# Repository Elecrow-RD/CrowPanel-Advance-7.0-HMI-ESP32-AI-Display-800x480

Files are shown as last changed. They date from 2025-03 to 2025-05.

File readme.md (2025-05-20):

## Menu
### 1, Product picture
### 2, Product version number
### 3, product information
### 4, Use the driver module
### 5,Quick Start
### 6,Folder structure.
### 7,Pin definition
### 8,Guidelines for downloading some of the files from the github repository

### 1, Product picture

Crowpanel Advance ESP32 HMI AI Display

#### 2, Product version number

| | Hardware | Software | Remark |
| ---- | --- | --- | --- |
| 1 | V1.0 | V1.0 | old |
| 2 | V1.2 | V1.2 | latest |

### 3, product information

| Main Chip-ESP32-S3-WROOM-1-N16R8 | |
| --- | --- |
| CPU/SoC | high-performance Xtensa 32-bit LX7 dual-core processor, with up to 240MHz |
| System Memory | 512KB SRAM、8M PSRAM |
| Memory | 16M Flash，384KB ROM |
| Development Language | MicroPython、C/C++ |
| Development Environment | ESP-IDF、Arduino IDE、PlatformIO、Micro Python、LVGL |
| **Screen** | |
| Size | 7.0 inch |
| Diver IC | SC7277 |
| Resolution | 800*480 |
| Display Panel | IPS Panel |
| Touch Panel | Capacitive Single Touch |
| Viewing Angle | 178° |
| Brightness | 400 cd/m²(Typ.) |
| Color Depth | 16-bit |
| **Wireless Communication - Onboard Antenna** | |
| WiFi | Support 2.4GHz, 802.11a/b/g/n |
| Bluetooth | Support Bluetooth 5.0 and BLE |
| Other | **Zigbee、LoRa、nRF2401、Matter、Thread and Wi-Fi 6 (Optional)** |
| **Interface/Function** | |
| Interface | USB port, UART, I2C, SD card slot, battery socket, speaker port, microphone, etc. |
| Function | RTC clock, audio amplifier, volume control, battery charge management, USB to UART, etc. |
| **Button/LED Indicator** | |
| Reset Button | Yes, press to reset the device |
| Boot Button | Yes, press and hold the power button to burn the program |
| PWR | Power indicator |
| CHG | Lithium battery charging status, completion indication |
| **Other** | |
| Installation method | Back hanging, fixed hole |
| Operating temperature | -20~70 °C |
| Storage temperature | -30~80 °C |
| Power Input | 5V/2A, USB or UART terminal |
| Active Area | 156mm*87mm |
| Dimensions | 181.26*108.36*16mm |

### 4, Use the driver module

| Name | dependency library |
| ---- | --- |
| LVGL | lvgl/lvgl@8.3.3 |
| | Adafruit GFX Library<br/>version=1.11.0 |

### 5,Quick Start
### Arduino IDE starts

#### Teaching Case Path：./example/example_code7.0

1.Download the library files used by this product to the 'libraries' folder.

C:\Users\Documents\Arduino\libraries\



2.Open the Arduino IDE



3.Open the code configuration environment and burn it



### ESP-IDF starts

#### Teaching Case Path：./example/idf_code

1.Right-click on an empty space in the project folder and select "Open with VS Code" to open the project.


2.In the IDF plug-in, select the port, then compile and flash


### 6,Folder structure.

|--3D file： Contains 3D model files (.stp) for the hardware. These files can be used for visualization, enclosure design, or integration into CAD software.

|--Datasheet: Includes datasheets for components used in the project, providing detailed specifications, electrical characteristics, and pin configurations.

|--Eagle_SCH&PCB: Contains **Eagle CAD** schematic (`.sch`) and PCB layout (`.brd`) files. These are used for circuit design and PCB manufacturing.

|--example: Provides example code and projects to demonstrate how to use the hardware and libraries. These examples help users get started quickly.

|--factory_firmware: Stores pre-compiled factory firmware that can be directly flashed onto the device. This ensures the device runs the default functionality.

|--factory_sourcecode:  Contains the source code for the factory firmware, allowing users to modify and rebuild the firmware as needed.

|--libraries: Includes necessary libraries required for compiling and running the project. These libraries provide drivers and additional functionalities for the hardware.

|--Squareline_studio Instructions for use: Squareline_studio instructions: Demonstrate the use of squareline studio.

### 7,Pin definition

#define HSPI_MISO  4
#define HSPI_MOSI  6
#define HSPI_SCLK  5
#define HSPI_SS    19

#define SD_MOSI 6
#define SD_MISO 4
#define SD_SCK  5
#define SD_CS   7 //The chip selector pin is not connected to IO

#define I2S_DOUT 12
#define I2S_BCLK 13
#define I2S_LRC 11

cfg.pin_sclk = 42;  // SPI、SCLK

cfg.pin_mosi = 39;  // SPI、CLK

cfg.pin_miso = -1;  // SPI、MISO

cfg.pin_dc = 41; 

#define TOUCH_GT911_SCL 16
#define TOUCH_GT911_SDA 15

### 8,Guidelines for downloading some of the files from the github repository

##### 1, open the link in your browser: https://downgit.github.io/

##### 2, paste the URL of the GitHub destination folder in the input box (example format: `https://github.com/username/repository name/tree/branch name/folder path`)

github_download1

##### 3, even a that way to download the file.

①Click the “Create Download Link” button to create a download link, copy the link and open it with your browser to download the contents of the corresponding folder directly.

github_download2

②Click Download, and you can also download it directly.

github_download3

#### Note: DownGit downloads are stored by default in **your browser's default downloads folder**, usually:

- **Windows**: `C:\Users\your username\Downloads\` (downloads folder)
- **macOS**: `~/Downloads/` (downloads folder)
- **Linux**: `~/Downloads/` (Downloads folder)

If you change the default download path in your browser, the file will be stored in the download location you set. You can find the downloaded file path in your browser's **Download History** (shortcut `Ctrl + J` or `Cmd + J`).

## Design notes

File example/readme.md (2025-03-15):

## **The basic tutorial case is divided into 1-11 lessons:**

1,Introduction to CrowPanel-Advance-HMI Screen

2,Introduce the screen user interface and external speakers for playing songs

3,Use LVGL library to create UI interface and light up lights

4,SD card stores images and displays them locally

5,Port Introduction

6,nRF2401 communication

7,wirelessmodule_lorawan

 8,Elementary chatbot（text-to-text）

 9,wirelessmodule_zigbee

 10,Build AI Chatbot

 11,LoRa Meshtastic

### Documentation tutorial link：

https://www.elecrow.com/pub/wiki/HMI_Display_course.html

### YouTube tutorial link:

https://www.youtube.com/playlist?list=PLwh4PlcPx2Gfrtm7TmlARyF4ccTmIy-gK

### Product purchase link:

https://www.elecrow.com/crowpanel-advance-7-0-hmi-esp32-ai-display-800x480-artificial-intelligent-ips-touch-screen-support-meshtastic-and-arduino-lvgl-micropython.ht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

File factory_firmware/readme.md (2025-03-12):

# How to install the factory demo firmware with flash download tool?

#### 1.Preparation:

- USB C cable
- Laptop/PC
- Crowpanel Advance HMI ESP32 AI Display
- Flash download tool

Check whether the materials on the PCBA board are defective. Such as less material, false welding, tin and other bad phenomena.

#### 2.Flash the firmware 

##### Step1 Connect the ESP32 display to the laptop/PC with USB-C cable. The power indicator will light up.

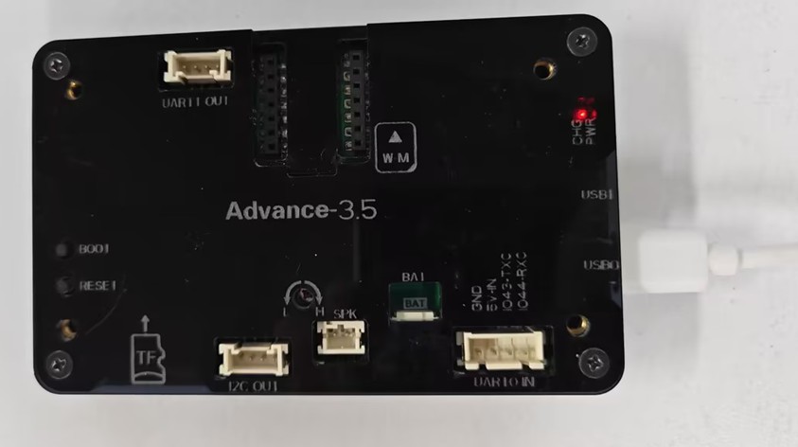
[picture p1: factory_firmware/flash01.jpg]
flash01


##### Step2 Open the flash download tool. 

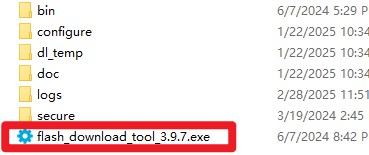
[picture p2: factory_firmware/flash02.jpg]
flash02


For the  Crowpanel Advance HMI ESP32 AI Display, the chip select ESP32-S3:

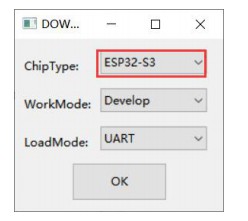
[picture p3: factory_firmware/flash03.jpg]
flash03


##### Step3

①Choose the firmware files;

flash0

②Enter the address: 

boot_app0.bin------0xe000

xxxx.ino.bin--------0x10000

xxxx.ino.bootloader.bin------0x0

xxxx.ino.partitions.bin-------0x8000

③Check the firmware files;

④Select the correct port number;

⑤Click “Start” to download

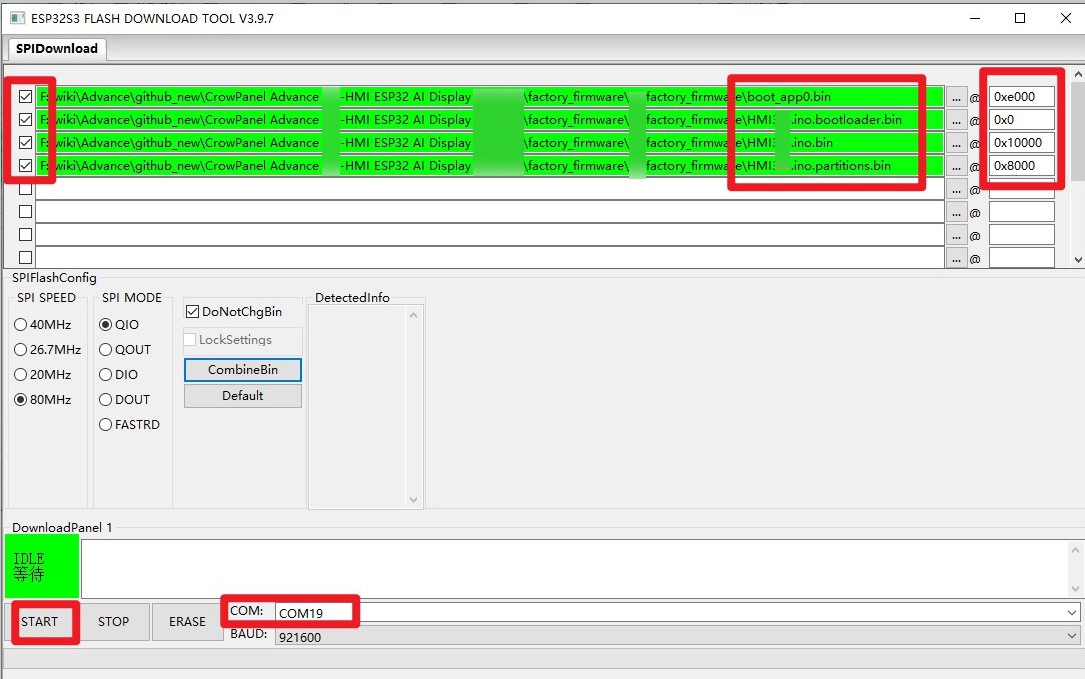
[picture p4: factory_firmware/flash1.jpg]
flash1


##### Step4 After the download is complete, blue FINISH will be displayed, and the progress bar at the bottom shows that it has come to an end.

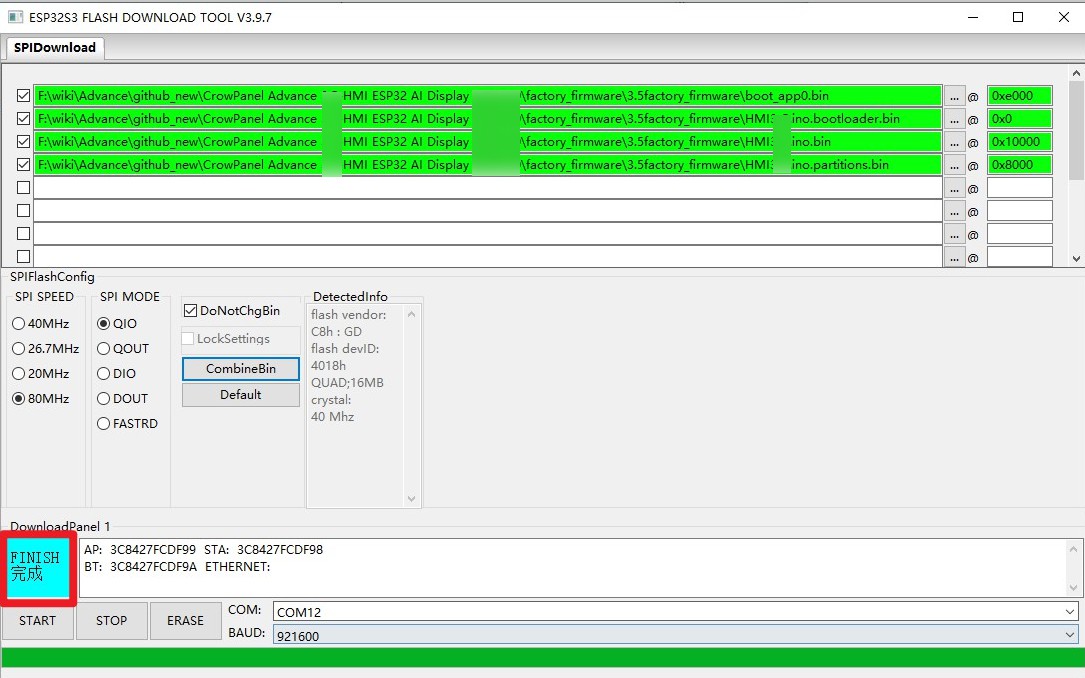
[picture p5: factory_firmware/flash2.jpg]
flash2


##### Step5 Press the reset button to show the demo.

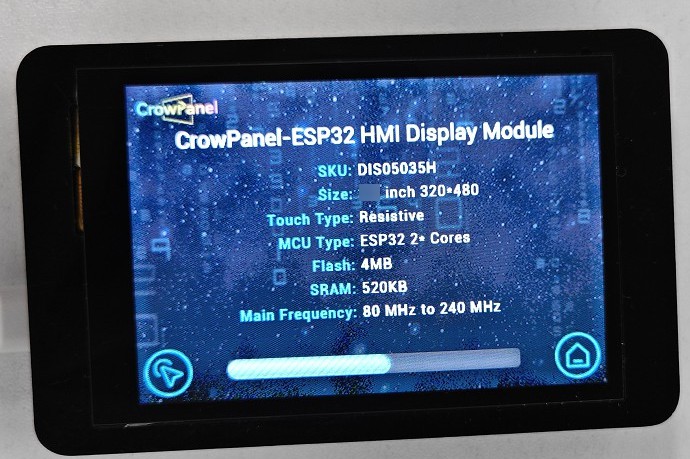
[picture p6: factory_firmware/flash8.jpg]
flash8


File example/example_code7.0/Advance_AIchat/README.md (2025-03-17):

# **AI real-time voice communication example**

we will integrate the CrowPanel Advance ESP32 display with a Large Language Model (LLM) and use a local computer running Python server code to process data. The processed data is then sent to the CrowPanel Advance AI display, which runs on Arduino code, for visualization. This setup enables seamless voice interaction with AI, showcasing the power of combining advanced hardware and software solutions.

***\*Note:\**** 

***\*ESP32 version 3.0.2\****

***\*Python version 3.10.6\****

### **How to use example**

You can find detailed video tutorials at the bottom of the page.

***\*First\****, identify the model you need to access and register an account on the model’s official website to obtain the access key.

***\*Then\**** uncomment the corresponding model code in the 'llm_openai.py' file and replace the placeholder with the key.

Ensure that your Python version is 3.10.6. Then, open the Command Prompt (or terminal) and navigate to the code folder. Run the following commands to create a virtual environment and install the related dependencies.



cmd

```
python -m venv venv
.\venv\Scripts\activate
python -m pip install --upgrade pip
pip install requrements-i
pip install openai dashscope
```

After installing the dependencies, you can run the 'ws.py' script to execute the saerver code.

The next step is to modify the ESP32 device code. We only need to change the server's IP address to ensure the device is on the same LAN as the WiFi network.



***\*Configuration parameter：\****



After burning successfully, the device will appear as connected on the server side and be ready to communicate. During communication, you can press the boot button to interrupt the current session and initiate a new one.

### **How to add Arduino libraries**

Replace the libraries file with the following path:

C:\Users\user name\Documents\Arduio\libraries

***\*Note\****: The 'user name' here is the same as the user computer account name.

## **Video tutorial link**：

 https://youtu.be/oIz41dyDqjo # **AI real-time voice communication example**

we will integrate the CrowPanel Advance ESP32 display with a Large Language Model (LLM) and use a local computer running Python server code to process data. The processed data is then sent to the CrowPanel Advance AI display, which runs on Arduino code, for visualization. This setup enables seamless voice interaction with AI, showcasing the power of combining advanced hardware and software solutions.

***\*Note:\**** 

***\*ESP32 version 3.0.2\****

***\*Python version 3.10.6\****

### **How to use example**

You can find detailed video tutorials at the bottom of the page.

***\*First\****, identify the model you need to access and register an account on the model’s official website to obtain the access key.

***\*Then\**** uncomment the corresponding model code in the 'llm_openai.py' file and replace the placeholder with the key.

Ensure that your Python version is 3.10.6. Then, open the Command Prompt (or terminal) and navigate to the code folder. Run the following commands to create a virtual environment and install the related dependencies.



cmd

```
python -m venv venv
.\venv\Scripts\activate
python -m pip install --upgrade pip
pip install requrements-i
pip install openai dashscope
```

After installing the dependencies, you can run the 'ws.py' script to execute the saerver code.

The next step is to modify the ESP32 device code. We only need to change the server's IP address to ensure the device is on the same LAN as the WiFi network.



***\*Configuration parameter：\****



After burning successfully, the device will appear as connected on the server side and be ready to communicate. During communication, you can press the boot button to interrupt the current session and initiate a new one.

### **How to add Arduino libraries**

Replace the libraries file with the following path:

C:\Users\user name\Documents\Arduio\libraries

***\*Note\****: The 'user name' here is the same as the user computer account name.

## **Video tutorial link**：

 https://youtu.be/oIz41dyDqjo

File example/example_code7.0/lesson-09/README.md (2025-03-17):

# **The ESP32-H2 module utilizes ZigBee technology to build a wireless Internet of Things** **example**

To complete this case, you need to refer to the detailed documentation tutorial, learn to burn code to utilizes ZigBee technology to build a wireless Internet and make the coordinator sends information to the terminal. Detailed documentation tutorials can be found at the bottom of the page.

***\*Note: All examples run on ESP32 version 3.0.2.\****

### **How to use example**

Learn how to set up the development board for serial communication with the wireless module. Learn how to use the official sample programs of ESP32-H2 to configure the wireless modules as a coordinator and a terminal node. After opening the sample code in the relevant code file with Arduino IDE.set the required configuration parameters and program it onto the development board.

***\*Configuration parameter：\****

For Coordinator configuration

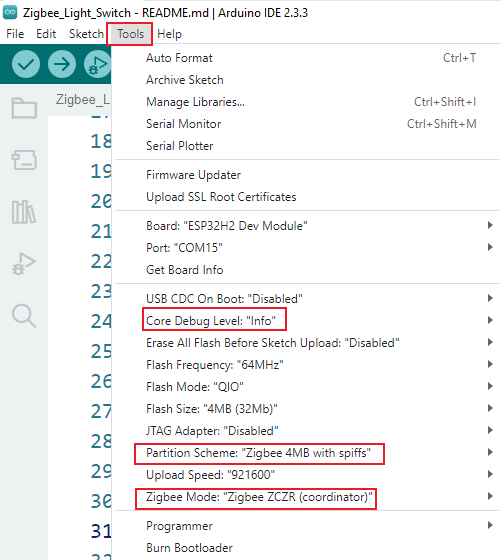
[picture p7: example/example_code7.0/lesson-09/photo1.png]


For Terminal device configuration

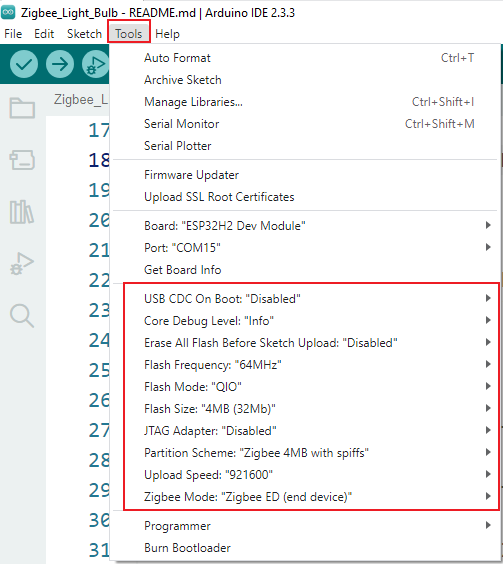
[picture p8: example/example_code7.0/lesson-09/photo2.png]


For HMI Advance AI Display Configuration

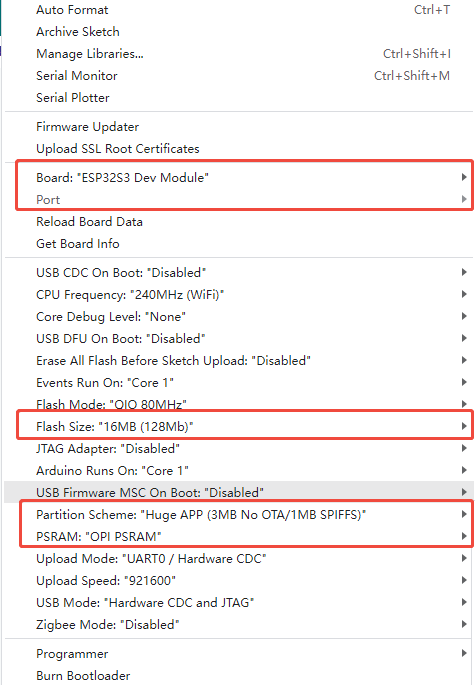
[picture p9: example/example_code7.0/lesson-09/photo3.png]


### **How to add Arduino libraries**

Replace the libraries file with the following path:

C:\Users\user name\Documents\Arduio\libraries

***\*Note\****: The 'user name' here is the same as the user computer account name.

## **Documentation tutorial link****：**

## https://www.elecrow.com/wiki/9.ZigBee.html

## **Video** **tutorial link****：**
https://www.youtube.com/watch?v=UfxxT23T_bk

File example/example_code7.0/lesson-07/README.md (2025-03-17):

# **The nRF2401 wireless module is used to receive and transmit signals** **example**

To complete this case, you need to refer to the detailed documentation tutorial, learn to connect to the gateway, and then burn code to send AT instructions. Detailed documentation tutorials can be found at the bottom of the page.

***\*Note: All examples run on ESP32 version 3.0.2.\****

### **How to use example**

Learn how to set up a gateway.After opening the sample code in the relevant code file with Arduino IDE.set the required configuration parameters and program it onto the development board

***\*Configuration parameter：\****

图片7-1

**Note**:Before burning the code, be sure to set the switch on the back of the product to WM mode(0 1).

### **How to add Arduino libraries**

Replace the libraries file with the following path:

C:\Users\user name\Documents\Arduio\libraries

***\*Note\****: The 'user name' here is the same as the user computer account name.

## **Documentation tutorial link**：

https://www.elecrow.com/pub/wiki/7.Advance_wirelessmodule_lorawan.html

## **Video** **tutorial link**：
https://youtu.be/7SWwTssfDV8

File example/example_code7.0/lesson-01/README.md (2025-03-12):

# **Hello world example**

This is a simple example of displaying “Hello world” in the serial debugging window using ESP32 version 3.0.2.

***\*Note: All subsequent examples run on ESP32 version 3.0.2.\****

### **How to use example**

After opening the sample code in the relevant code file with Arduino IDE, set the required configuration parameters and program it onto the development board

***\*Configuration parameter：\****



### **How to add Arduino libraries**

No additional libraries are required for this lesson, so no imports are needed.

## **Documentation tutorial link**：

https://www.elecrow.com/pub/wiki/1_Introduction_to_CrowPanel-Advance-HMI_Screen.html

## **Video** **tutorial link**：

https://www.youtube.com/watch?v=W3LHGZRx7Jw&list=PLwh4PlcPx2Gfrtm7TmlARyF4ccTmIy-gK&index=1&t=42s

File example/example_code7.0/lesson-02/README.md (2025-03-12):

# **Play Internet music example**

This is an example of a program that uses a speaker to play an MP3 file from the Internet.

***\*Note: All examples run on ESP32 version 3.0.2.\****

### **How to use example**

After opening the sample code in the relevant code file with Arduino IDE.

Set up your wifi in code.

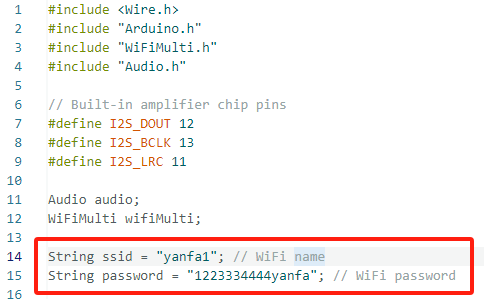
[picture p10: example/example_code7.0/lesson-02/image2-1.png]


set the required configuration parameters and program it onto the development board

***\*Configuration parameter：\****



After burning the program successfully, insert the speaker into the designated port on the development board.

**Note**:Before burning the code, be sure to set the switch on the back of the product to MIC&SPK mode(0 0).

### **How to add Arduino libraries**

Replace the libraries file with the following path:

C:\Users\user name\Documents\Arduio\libraries

***\*Note\****: The 'user name' here is the same as the user computer account name.

## **Documentation tutorial link**：

https://www.elecrow.com/pub/wiki/4.3_2_Introduce_the_screen_user_interface_and_external_speakers_for_playing_songs.html

## **Video** **tutorial link**：

https://www.youtube.com/watch?v=1lY-Cu6dnaQ&list=PLwh4PlcPx2Gfrtm7TmlARyF4ccTmIy-gK&index=2

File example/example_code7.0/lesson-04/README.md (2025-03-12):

# **Use an SD card to store and display pictures on the device example**

In this case, images are stored on an SD card and displayed on the Advanced AI screen.

***\*Note: All examples run on ESP32 version 3.0.2.\****

### **How to use example**

After opening the sample code in the relevant code file with Arduino IDE.set the required configuration parameters and program it onto the development board

***\*Configuration parameter：\****

图片4-1

**Note**:Before burning the code, be sure to set the switch on the back of the product to TF Card mode(1 0).

### **How to add Arduino libraries**

Replace the libraries file with the following path:

C:\Users\user name\Documents\Arduio\libraries

***\*Note\****: The 'user name' here is the same as the user computer account name.

## **Documentation tutorial link**：

https://www.elecrow.com/pub/wiki/4.3_4_SD_card_stores_images_and_displays_them_locally.html

## **Video** **tutorial link**：

https://www.youtube.com/watch?v=qSlhvBrq0_w&list=PLwh4PlcPx2Gfrtm7TmlARyF4ccTmIy-gK&index=4

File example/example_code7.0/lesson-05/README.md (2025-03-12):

# ****Connect to the sensor via the port to read temperature and humidity measurements example****

In this case, we connect the temperature and humidity sensor through the port to obtain the environmental temperature and humidity, and display the data on the Advanced AI screen in real time.

***\*Note: All examples run on ESP32 version 3.0.2.\****

### **How to use example**

After opening the sample code in the relevant code file with Arduino IDE.set the required configuration parameters and program it onto the development board

***\*Configuration parameter：\****

图片5-1

### **How to add Arduino libraries**

Replace the libraries file with the following path:

C:\Users\user name\Documents\Arduio\libraries

***\*Note\****: The 'user name' here is the same as the user computer account name.

## **Documentation tutorial link**：

https://www.elecrow.com/pub/wiki/4.3_5_Port_Introduction.html

## **Video** **tutorial link**：

https://www.youtube.com/watch?v=WM8ZcJ9OYKw&list=PLwh4PlcPx2Gfrtm7TmlARyF4ccTmIy-gK&index=5

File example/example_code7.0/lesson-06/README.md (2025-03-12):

# **The nRF2401 wireless module is used to receive and transmit signals** **example**

In this case, two nRF24L01 wireless modules are employed, with one module transmitting signals and the other receiving signals.

***\*Note: All examples run on ESP32 version 3.0.2.\****

### **How to use example**

After opening the sample code in the relevant code file with Arduino IDE.set the required configuration parameters and program it onto the development board

***\*Configuration parameter：\****

图片6-1

**Note**:Before burning the code, be sure to set the switch on the back of the product to WM mode(0 1).

### **How to add Arduino libraries**

Replace the libraries file with the following path:

C:\Users\user name\Documents\Arduio\libraries

***\*Note\****: The 'user name' here is the same as the user computer account name.

## **Documentation tutorial link**：

https://www.elecrow.com/pub/wiki/4.3_6_NRF2401_communication.html

## **Video** **tutorial link**：

https://www.youtube.com/watch?v=PHzW8t038Qo&list=PLwh4PlcPx2Gfrtm7TmlARyF4ccTmIy-gK&index=6

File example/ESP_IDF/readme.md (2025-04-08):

##### ESP_IDF code program are in the google disk, please click on the link to download it directly!

#### link：

https://drive.google.com/drive/folders/1hEXyH14QeDgVdENxUfiYBQVCTbMbI6v9?usp=sharing

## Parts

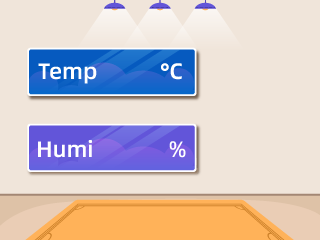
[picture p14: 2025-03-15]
example/example_code7.0/lesson-05/source material/320x240/background.png

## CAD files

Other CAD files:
Datasheet/LI070DE42Y_0812.dwg

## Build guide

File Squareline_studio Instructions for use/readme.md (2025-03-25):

# Use SquareLine Studio and LVGL libraries to create a UI interface to light the lights

## **1.** Introduce LVGL

------

LVGL (LittlevGL) is an open-source, lightweight, high-performance embedded graphics library designed specifically for devices with limited resources. It supports multi platform porting, provides rich controls, animations, touch support, and highly customizable styles, suitable for fields such as smart homes, industrial equipment, medical instruments, etc. LVGL is centered around modular design and can run on bare metal or operating systems, accelerating GUI development through powerful community support and tools such as SquareLine Studio.



SquareLine Studio is a next-generation user interface (UI) solution for individuals and professionals, allowing users to quickly and easily design and develop aesthetically pleasing UI for embedded devices. This software provides integrated design, prototyping, and development capabilities, supporting the export of platform independent C or MicroPython code for LVGL (Lightweight Graphics Library), which can be compiled and run on any vendor's device.



## 2.Install SquareLine Studio

------

### **2.1** Installation Guide

Enter the https://squareline.io/ to download the SquareLine installation file.



Download the version 1.4.0



Double-click the setup.exe file.



Click install.



Wait for installation.



Installation finish.



There is a 30-day trial period for the first time you use it. Please follow the prompts to register an account. You will continue to use it when you log in to your account next time.



### **2.2** Software Function Introduction

Open the software

The historical project page: open the project built earlier.



Create a project page: choose different platforms according to different hardware of the project.



###### When select the Arduino framwork, there's only one option "Arduino with TFT_eSPI". By choosing this, the squareline studio will generate a template code suitable for the TFT_eSPI library. However, squareline studio not only supports the TFT_eSPI library, it supports a variety of libraries to suit different hardware and application needs. For example, Adafruit_GFX library, LovyanGFX etc.[¶](https://www.elecrow.com/pub/wiki/3.5_3_Use_LVGL_library_to_create_UI_interface_and_light_up_lights.html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)

###### After using SLS to generate UI code, we then use different graphics libraries according to different hardware and modify the corresponding code to display the content you design.[¶](https://www.elecrow.com/pub/wiki/3.5_3_Use_LVGL_library_to_create_UI_interface_and_light_up_lights.html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)

Example page. This page has several official examples for reference.



The project settings bar is used to make basic settings for the project, including property settings such as project name, screen size, display angle, etc.



###### Note： Please select the corresponding resolution and color depth according to the screen specifications.[¶](https://www.elecrow.com/pub/wiki/3.5_3_Use_LVGL_library_to_create_UI_interface_and_light_up_lights.html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)



##### ①Toolbar, including File, Export, and Help. Basic file operation bar, create or open files, export UI files and other operations. Click help and there are related introductory documents.

##### ②Screen bar, the project screen will be listed here.

##### ③Widget area, all widgets are here and can be selected and used according to project needs.

##### ④Hierarchy area, it will show every widget used in each screen.

##### ⑤This area shows the actual display effect, you can adjust the widgets or screen here.

##### ⑥Material column, the added materials are displayed here.

##### ⑦Setting bar, where you can make basic settings for each part, including the basic attributes and trigger operations of the part.

##### ⑧Theme bar, different themes can be set.

## 3 Use SquareLine Studio to create UI control interfaces

------

Firstly, open the SquareLine Studio software and create a case study



Choose the correct resolution based on the different sizes you are using



Here, I take a 5.0-inch screen as an example. After determining the resolution, I fill it in



After selecting the parameters, click Create



Open the photo of the desk lamp we provided and add it in. (Of course, you can also choose the image you want to use)





The lamp_28 image size is available for both 2.4-inch and 2.8-inch screens.

Table_1amp image sizes are available for 3.5-inch, 4.3-inch, 5.0-inch, and 7-inch screens.



After adding it, drag and drop the image in.



The task we need to complete is to turn on and off the lights by clicking on the buttons on the graphical interface. So we need to design two buttons

From the left sidebar, select Button and drag it into the interface.



You can adjust the border of the button with the mouse, which can adjust the size of the button, and you can also drag and drop the button to adjust its position.

Then, by selecting Background, choose the background color of the Button.





We have made the button patterns, and now we need to add labels to the button patterns in order to distinguish their functions.

Drag and drop from the left sidebar, select Label, and drag into the interface.



Modify the text content of the label



And modify the font size and text color of the text



The Button and Label have been designed. Click on the Hierarchy in the right-hand column and drag the Label onto the Button line to merge them into one.



At this point, if you drag the buttons again, you will find that they are dragged together

Next, we will copy a completed button, right-click, and paste it in.







Click the second button ON to change the text content to Off. Used to achieve the effect of turning off lights.



## **4** Add functions to the buttons to enable them to turn on and off lights

------

Select 'event' to add in the right sidebar



Select 'released' as the triggering condition and 'Call function' as the action.



After selecting, click ADD.

And add a function name to the CALL Function. (Customization is sufficient)



Similarly, add an event to the Off button. The operation process is the same as above.



After adding, run





## **5** UI interface design completed, exporting UI files for easy use in subsequent code

------

Click on Project Setting



Set export path





Complete the setup and export file



Copy and paste the exported code into the code folder we need to open





Then double-click BigInch_LVGL.ino and open it using Arduino IDE

## **6 Connect the light bulb and add code to control the light bulb to turn on and off**

------

Connect the light bulb at the UART1 interface



Observing the schematic diagram of this size, it is known that the pin for UART1 to control the light bulb to turn on and off is 19





A large-sized screen requires setting 19 pins as the output mode.

(Due to the fact that pin 19 in the circuit of large-sized products controls both the wireless module and the UART1 interface, it is necessary to switch the mode to 0 1)





And add the function of turning on and off the light bulb in the ui_ event. c file.

(When the On button is clicked, the light is on; when the Off button is clicked, the light is off)



## **7 Configure the code running environment and upload the code**

------

(!! Before uploading the code, please use different library files according to the size you are using. You can review the content of Lesson 2)

(For large-sized screens of 4.3 inches, 5.0 inches, and 7.0 inches, be sure to switch the mode to 0 1 state before uploading the code, because the pins of UART1 and W-M mode are both used in 0 1 mode, so that you can use the pins of UART1)





So you can see the UI interface you just designed



You can click the On and Off buttons to control the on/off of the lights





## 8 Code presentation

------

### 7.0 inches, 5.0 inches, 4.3 inches

```
#include "pins_config.h"
#include "LovyanGFX_Driver.h"

#include <Arduino.h>
#include <lvgl.h>
#include <Wire.h>
#include <SPI.h>

#include <stdbool.h>
#include <Adafruit_SSD1306.h>
#include <Adafruit_GFX.h>

/* Expand IO */
#include <TCA9534.h>
TCA9534 ioex;

LGFX gfx;

/* Change to your screen resolution */
static lv_disp_draw_buf_t draw_buf;
static lv_color_t *buf;
static lv_color_t *buf1;

uint16_t touch_x, touch_y;

//  Display refresh
void my_disp_flush(lv_disp_drv_t *disp, const lv_area_t *area, lv_color_t *color_p) {
  if (gfx.getStartCount() > 0) {
    gfx.endWrite();
  }
  gfx.pushImageDMA(area->x1, area->y1, area->x2 - area->x1 + 1, area->y2 - area->y1 + 1, (lgfx::rgb565_t *)&color_p->full);

  lv_disp_flush_ready(disp);  //    Tell lvgl that the refresh is complete
}

//  Read touch
void my_touchpad_read( lv_indev_drv_t * indev_driver, lv_indev_data_t * data )
{
  data->state = LV_INDEV_STATE_REL;// The state of data existence when releasing the finger
  bool touched = gfx.getTouch( &touch_x, &touch_y );
  if (touched)
  {
    data->state = LV_INDEV_STATE_PR;

    //  Set coordinates
    data->point.x = touch_x;
    data->point.y = touch_y;
  }
}

void setup()
{
  Serial.begin(115200); 

  pinMode(19, OUTPUT);

  Wire.begin(15, 16);
  delay(50);

  ioex.attach(Wire);
  ioex.setDeviceAddress(0x18);
  ioex.config(1, TCA9534::Config::OUT);
  ioex.config(2, TCA9534::Config::OUT);
  ioex.config(3, TCA9534::Config::OUT);
  ioex.config(4, TCA9534::Config::OUT);

  /* Turn on backlight*/
  ioex.output(1, TCA9534::Level::H);

  // GT911 power on timing ->Select 0x5D
  pinMode(1, OUTPUT);
  digitalWrite(1, LOW);
  ioex.output(2, TCA9534::Level::L);
  delay(20);
  ioex.output(2, TCA9534::Level::H);
  delay(100);
  pinMode(1, INPUT);
  /*end*/

  // Init Display
  gfx.init();
  gfx.initDMA();
  gfx.startWrite();
  gfx.fillScreen(TFT_BLACK);

  lv_init();
  size_t buffer_size = sizeof(lv_color_t) * LCD_H_RES * LCD_V_RES;
  buf = (lv_color_t *)heap_caps_malloc(buffer_size, MALLOC_CAP_SPIRAM);
  buf1 = (lv_color_t *)heap_caps_malloc(buffer_size, MALLOC_CAP_SPIRAM);

  lv_disp_draw_buf_init(&draw_buf, buf, buf1, LCD_H_RES * LCD_V_RES);

  // Initialize display
  static lv_disp_drv_t disp_drv;
  lv_disp_drv_init(&disp_drv);
  // Change the following lines to your display resolution
  disp_drv.hor_res = LCD_H_RES;
  disp_drv.ver_res = LCD_V_RES;
  disp_drv.flush_cb = my_disp_flush;
  disp_drv.draw_buf = &draw_buf;
  lv_disp_drv_register(&disp_drv);

  // Initialize input device driver program
  static lv_indev_drv_t indev_drv;
  lv_indev_drv_init(&indev_drv);
  indev_drv.type = LV_INDEV_TYPE_POINTER;
  indev_drv.read_cb = my_touchpad_read;
  lv_indev_drv_register(&indev_drv);

  delay(100);

  gfx.fillScreen(TFT_BLACK);
  // lv_demo_widgets();// Main UI interface
  ui_init();

  Serial.println( "Setup done" );
}

void loop()
{
  lv_timer_handler(); /* let the GUI do its work */
  delay(1);
}
```

**If your code compiles incorrectly, you can check if the ESP32 version number is correct. The ESP32 version number we need for this lesson is 3.0.2.**

new-1

**Secondly, please pay attention to replacing the corresponding size library file.**

**Select the appropriate library file based on the product screen size**

Path reference：C:\ESP32_Code\CrowPanel_Advanced_HMI\Arduino_lib Series Library

new-2

**I will use the Advance 7.0-inch product as an example for operation**

Copy the Libraries Advanced 7.0 folder

Open Arduino IDE runtime library file path

Reference path: C:\Users\14175\Documents\Arduino

new-3

Delete the existing libraries folder

new-4

Paste the copied library Advanced 7.0 folder into this path

new-5

Change the folder name to the original libraries

new-6

Library update completed, restart Arduino IDE.

**When using other sizes, changing the library file is the same operation**

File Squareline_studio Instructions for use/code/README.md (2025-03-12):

# **The touch screen lights up LED lights example**

This is an example of using the LVGL library to display an icon on the Advance AI screen, and to control the LED light when the icon is pressed.

***\*Note: All examples run on ESP32 version 3.0.2.\****

### **How to use example**

After opening the sample code in the relevant code file with Arduino IDE.set the required configuration parameters and program it onto the development board

***\*Configuration parameter：\****

图片3-1

### **How to add Arduino libraries**

Replace the libraries file with the following path:

C:\Users\user name\Documents\Arduio\libraries

***\*Note\****: The 'user name' here is the same as the user computer account name.

## **Documentation tutorial link**：

https://www.elecrow.com/pub/wiki/4.3_3_Use_LVGL_library_to_create_UI_interface_and_light_up_lights.html

## **Video** **tutorial link**：

https://www.youtube.com/watch?v=LXoKEsqQGDk&list=PLwh4PlcPx2Gfrtm7TmlARyF4ccTmIy-gK&index=3

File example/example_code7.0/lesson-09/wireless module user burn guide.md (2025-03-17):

## Wirless Module H2/C6 Single Board Burn-in Method

### 1.Tools to be prepared

| | Tools | quantities |
| ---- | --- | --- |
| 1 | Single Female DuPont Cable | 4 |
| 2 | Serial Module Tools | 1 |
| 3 | Wirless Module H2/C6 | 1 |
| 4 | Soldering Iron & Wire | |

 Single Female DuPont Cable
 


Wirless Module H2/C6



Serial modules (CH340/CP2102, etc. are fine)



### 2.Weld line.

The burn-in pins for the Wirless Module H2/C6 are the same, and the four wires that need to be soldered are located as follows：

（Arrow pointing up）

| RX | TX |
| ---- | ---- |
| | |
| | |
| | |
| 3V3  | |
| GND  | |
| | |

Module Pin Definition

The finished soldering is shown below.





### 3.Burning

RX is connected to TX of the serial module;

TX connection to the RX of the serial module;

3V3 connection to the 3V3 of the serial module;

GND connection to the GND of the serial module.

Connect the serial module to the computer and find the corresponding serial device number (e.g. COM7) in the Task Manager.



Open Arduino or open the corresponding serial port under any serial port tool.



Press and hold the BOOT key and then press the RST key to enter burn mode.



The serial monitor prints to enter burn-in mode.


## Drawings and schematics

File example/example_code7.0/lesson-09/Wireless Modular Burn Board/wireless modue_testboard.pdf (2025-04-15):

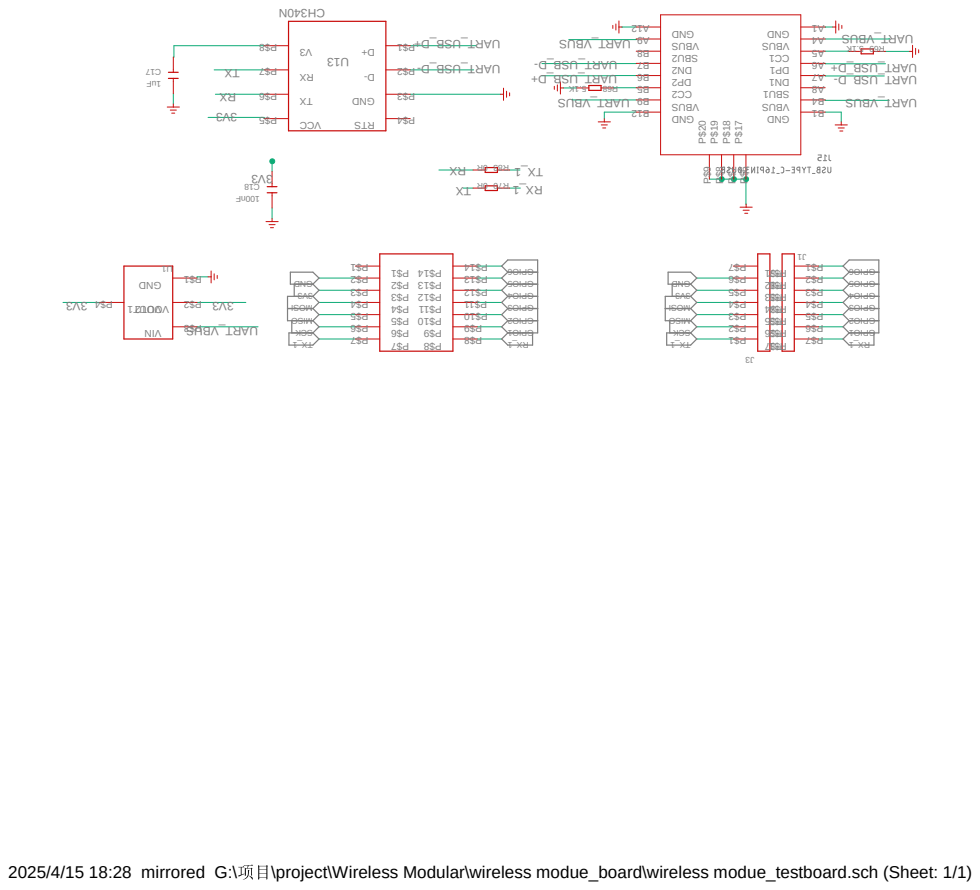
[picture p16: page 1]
2025/4/15 18:28 mirrored G:\; \project\Wireless Modular\wireless modue_board\wireless modue_testboard.sch (Sheet: 1/1); DNG 1A SUBV; 4A 1 CC 5A 1PD 6A 1 ND 7A 1 UBS; SUBV; 4B DNG 1B; DNG 21B; 2 UBS; DNG 21A; DNG 3$P; STR 4$P; CCV; DNG 1$P; 1TUOV; 2TUOV; DNG DNG; - D_BSU_TRAU; + D_BSU_TRAU; + D_BSU_TRAU SUBV_TRAU; SUBV_TRAU SUBV_TRAU; SUBV_TRAU; 3V3 3V3 3V3 I SOM I SOM OSI M OSI M

KCS 1 OI PG

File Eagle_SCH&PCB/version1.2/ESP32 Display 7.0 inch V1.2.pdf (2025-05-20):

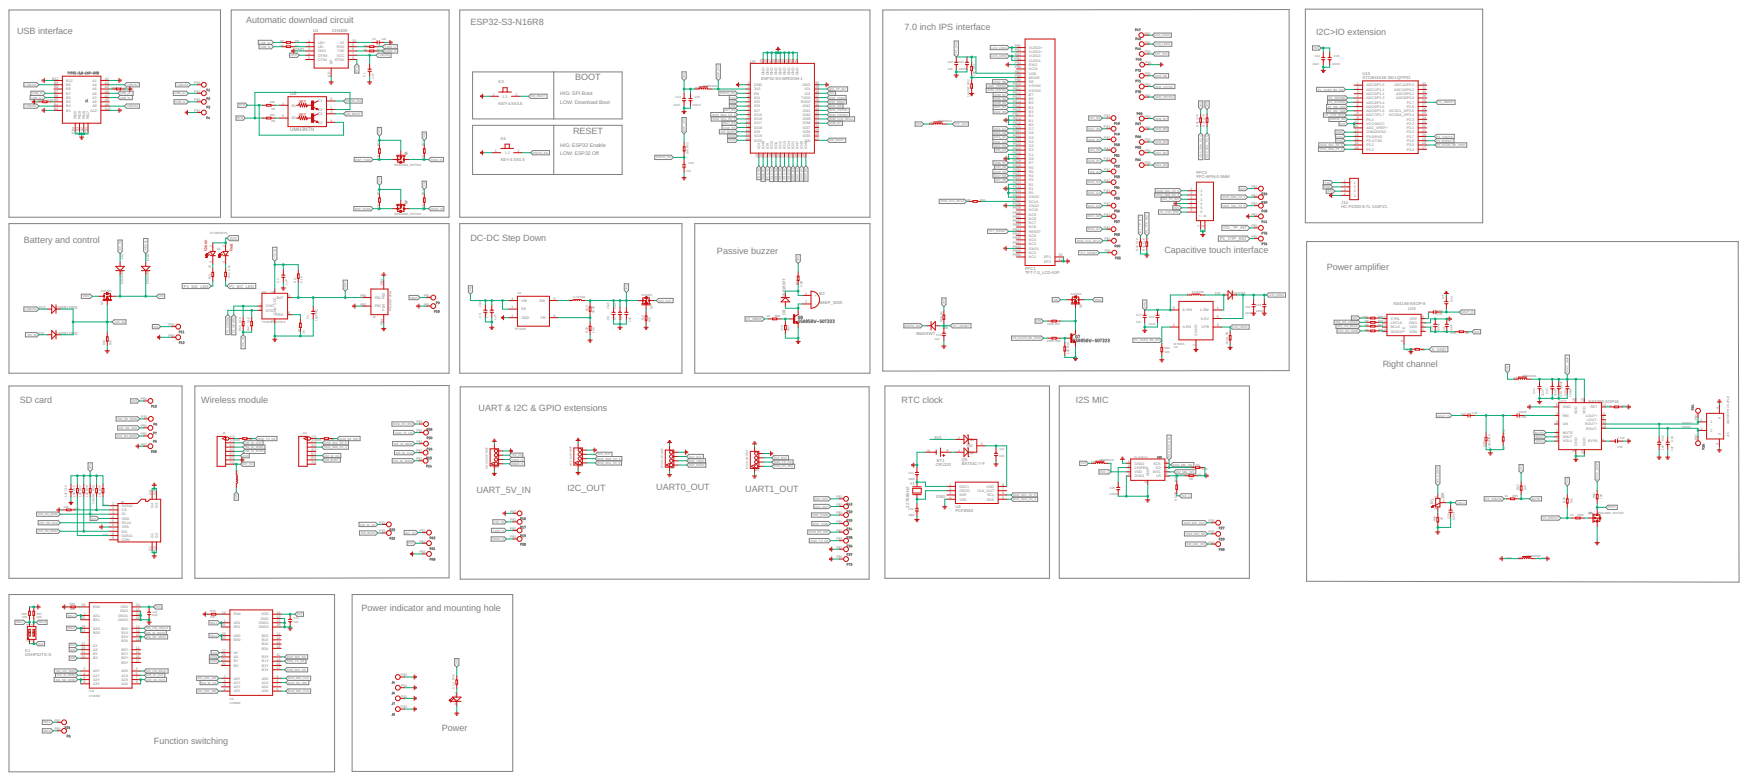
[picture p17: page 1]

DC-DC Step Down

Power indicator and mounting hole

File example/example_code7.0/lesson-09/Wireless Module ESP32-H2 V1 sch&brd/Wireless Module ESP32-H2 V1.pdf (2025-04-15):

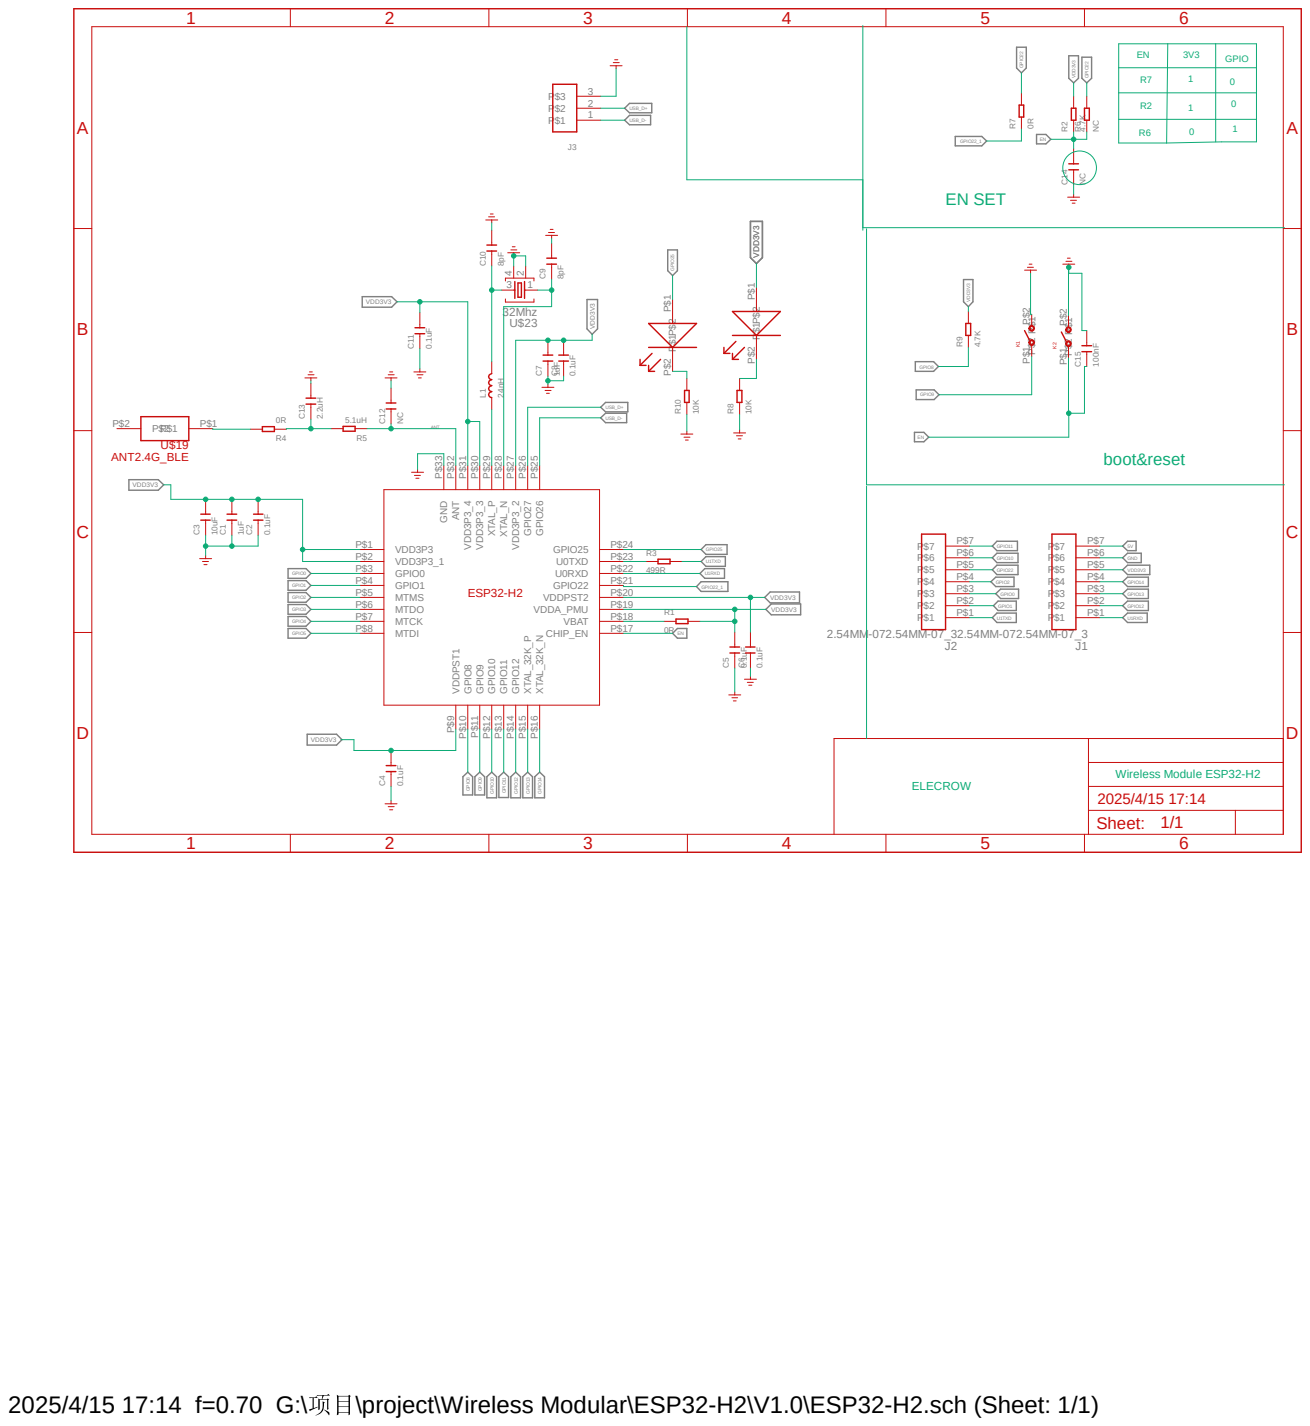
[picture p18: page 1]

EN | 3V3 | GPIO

EN SET

ELECROW

Sheet: 1/1

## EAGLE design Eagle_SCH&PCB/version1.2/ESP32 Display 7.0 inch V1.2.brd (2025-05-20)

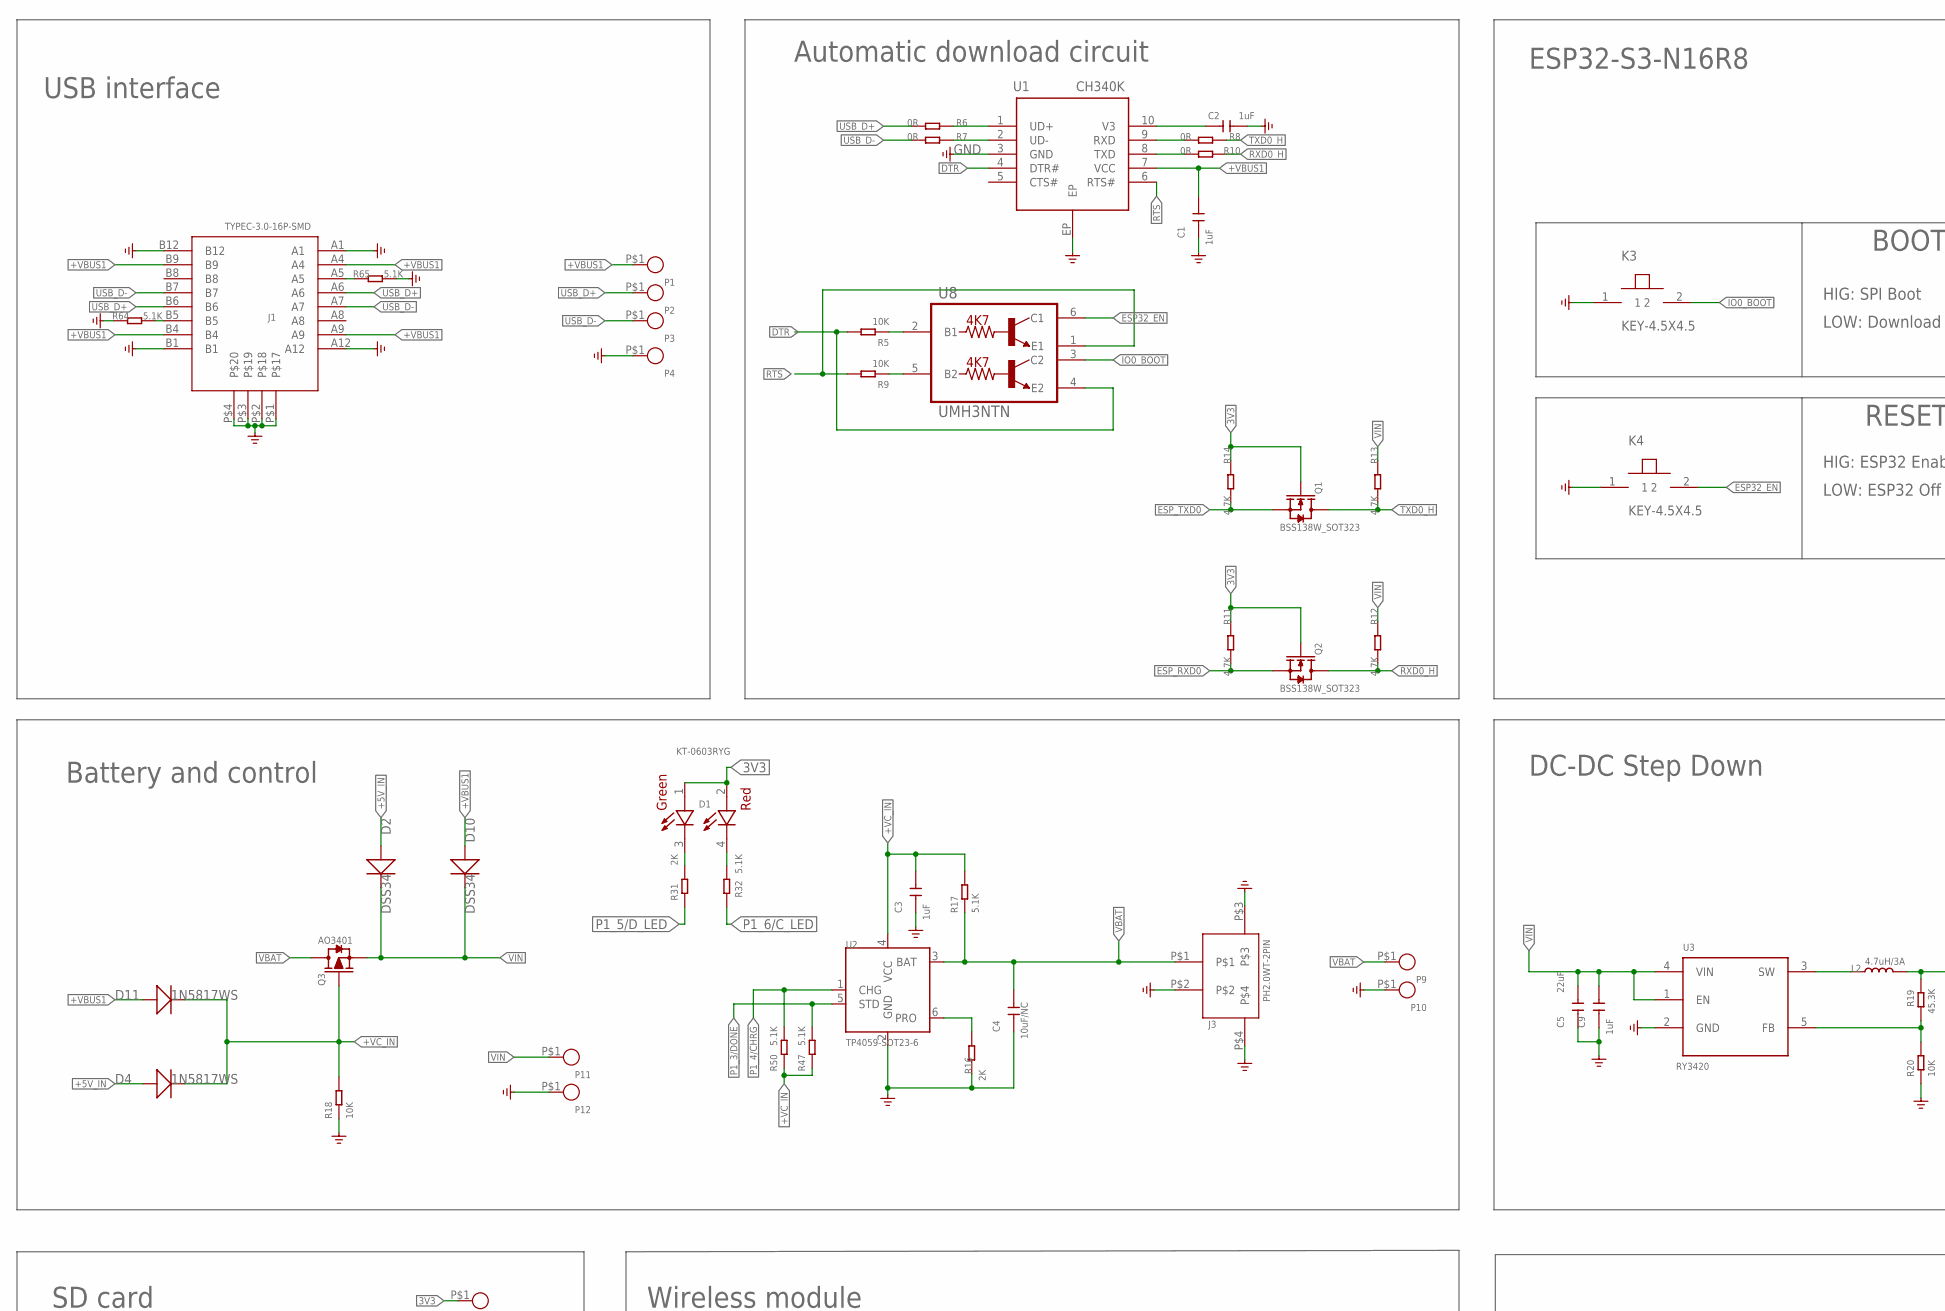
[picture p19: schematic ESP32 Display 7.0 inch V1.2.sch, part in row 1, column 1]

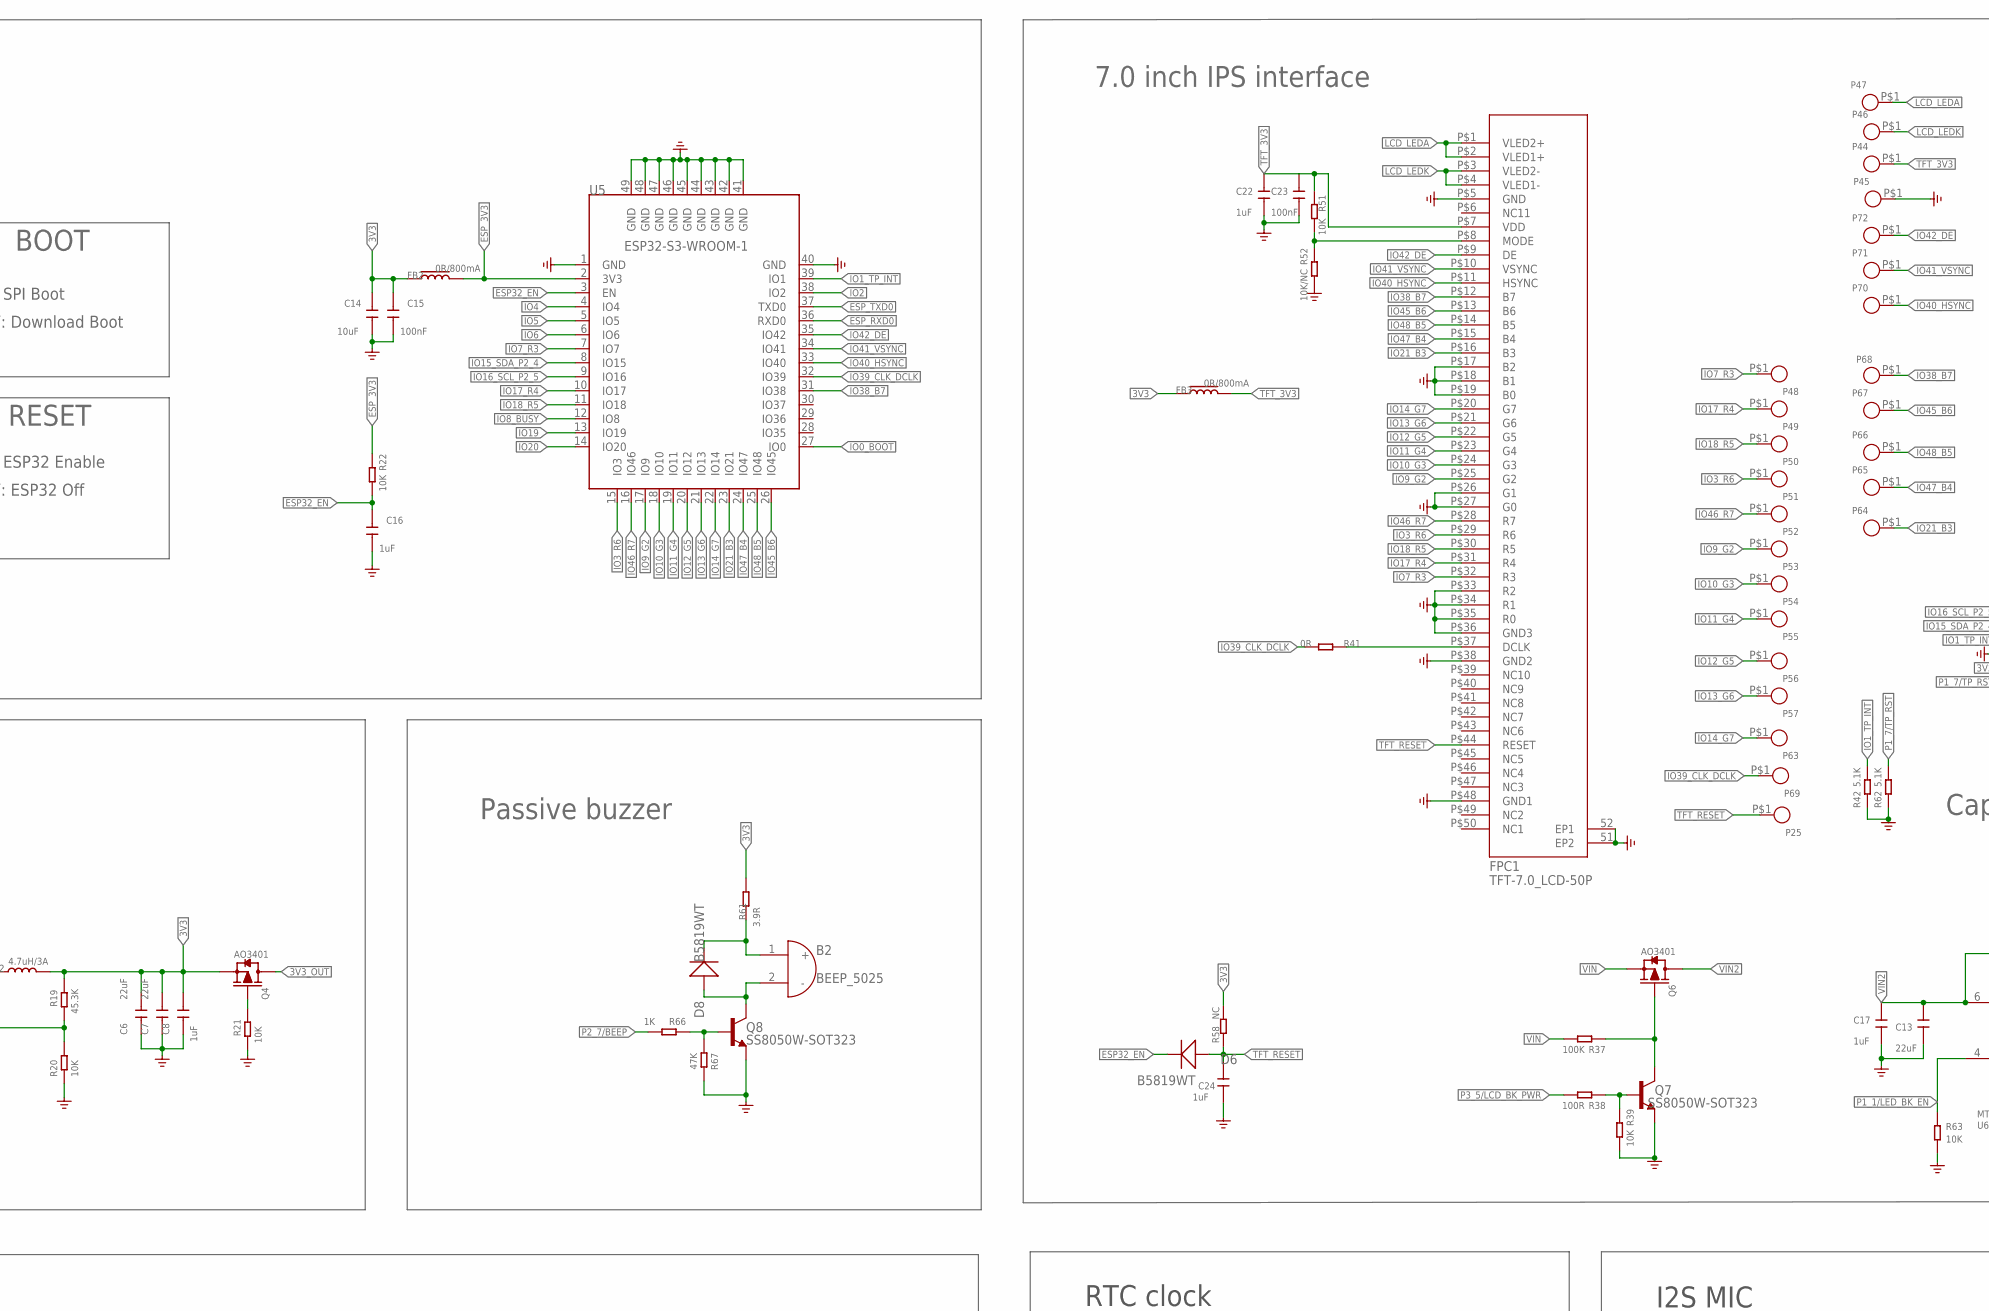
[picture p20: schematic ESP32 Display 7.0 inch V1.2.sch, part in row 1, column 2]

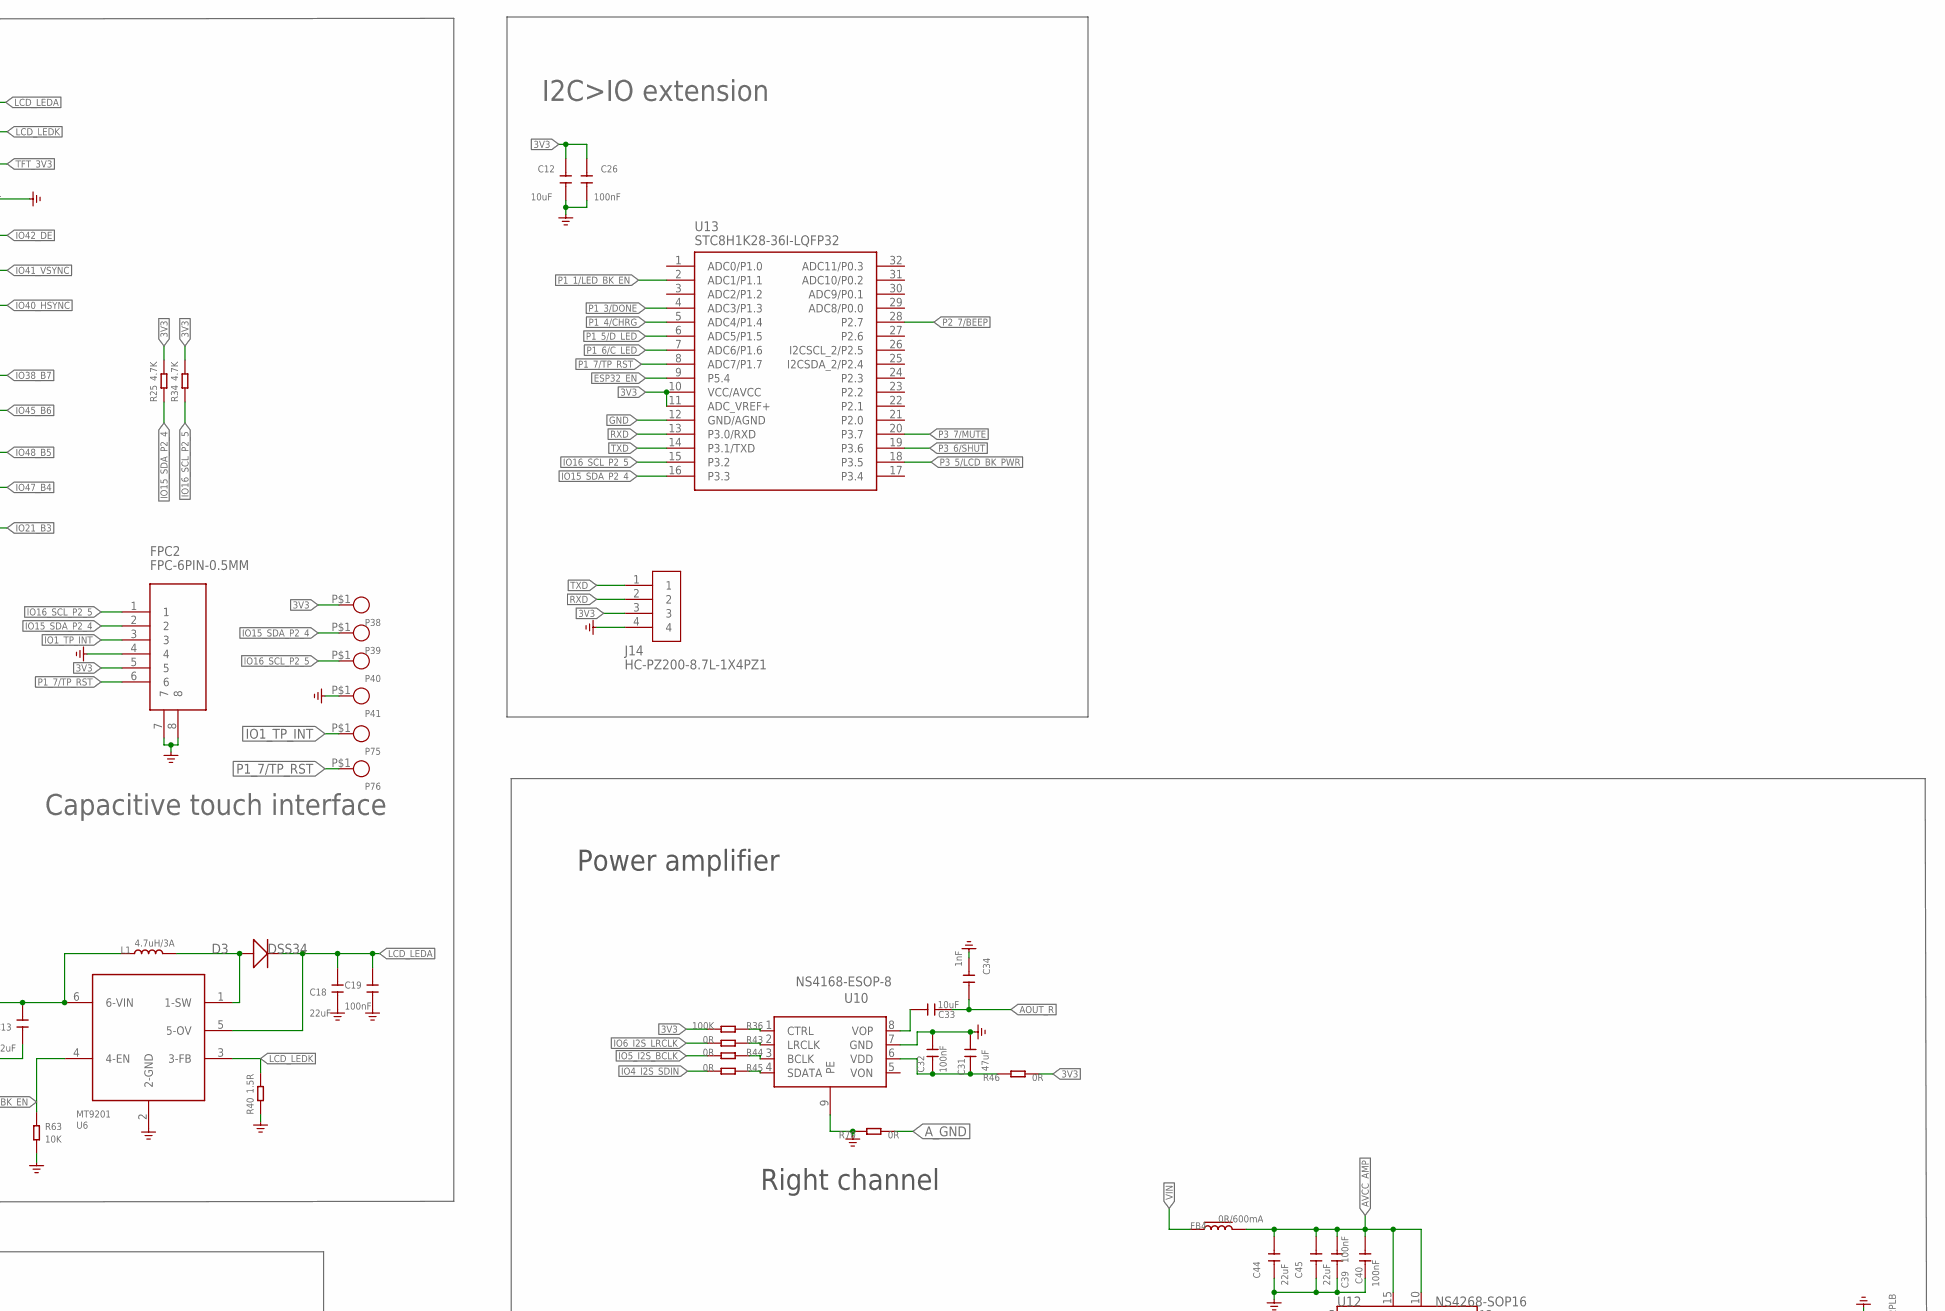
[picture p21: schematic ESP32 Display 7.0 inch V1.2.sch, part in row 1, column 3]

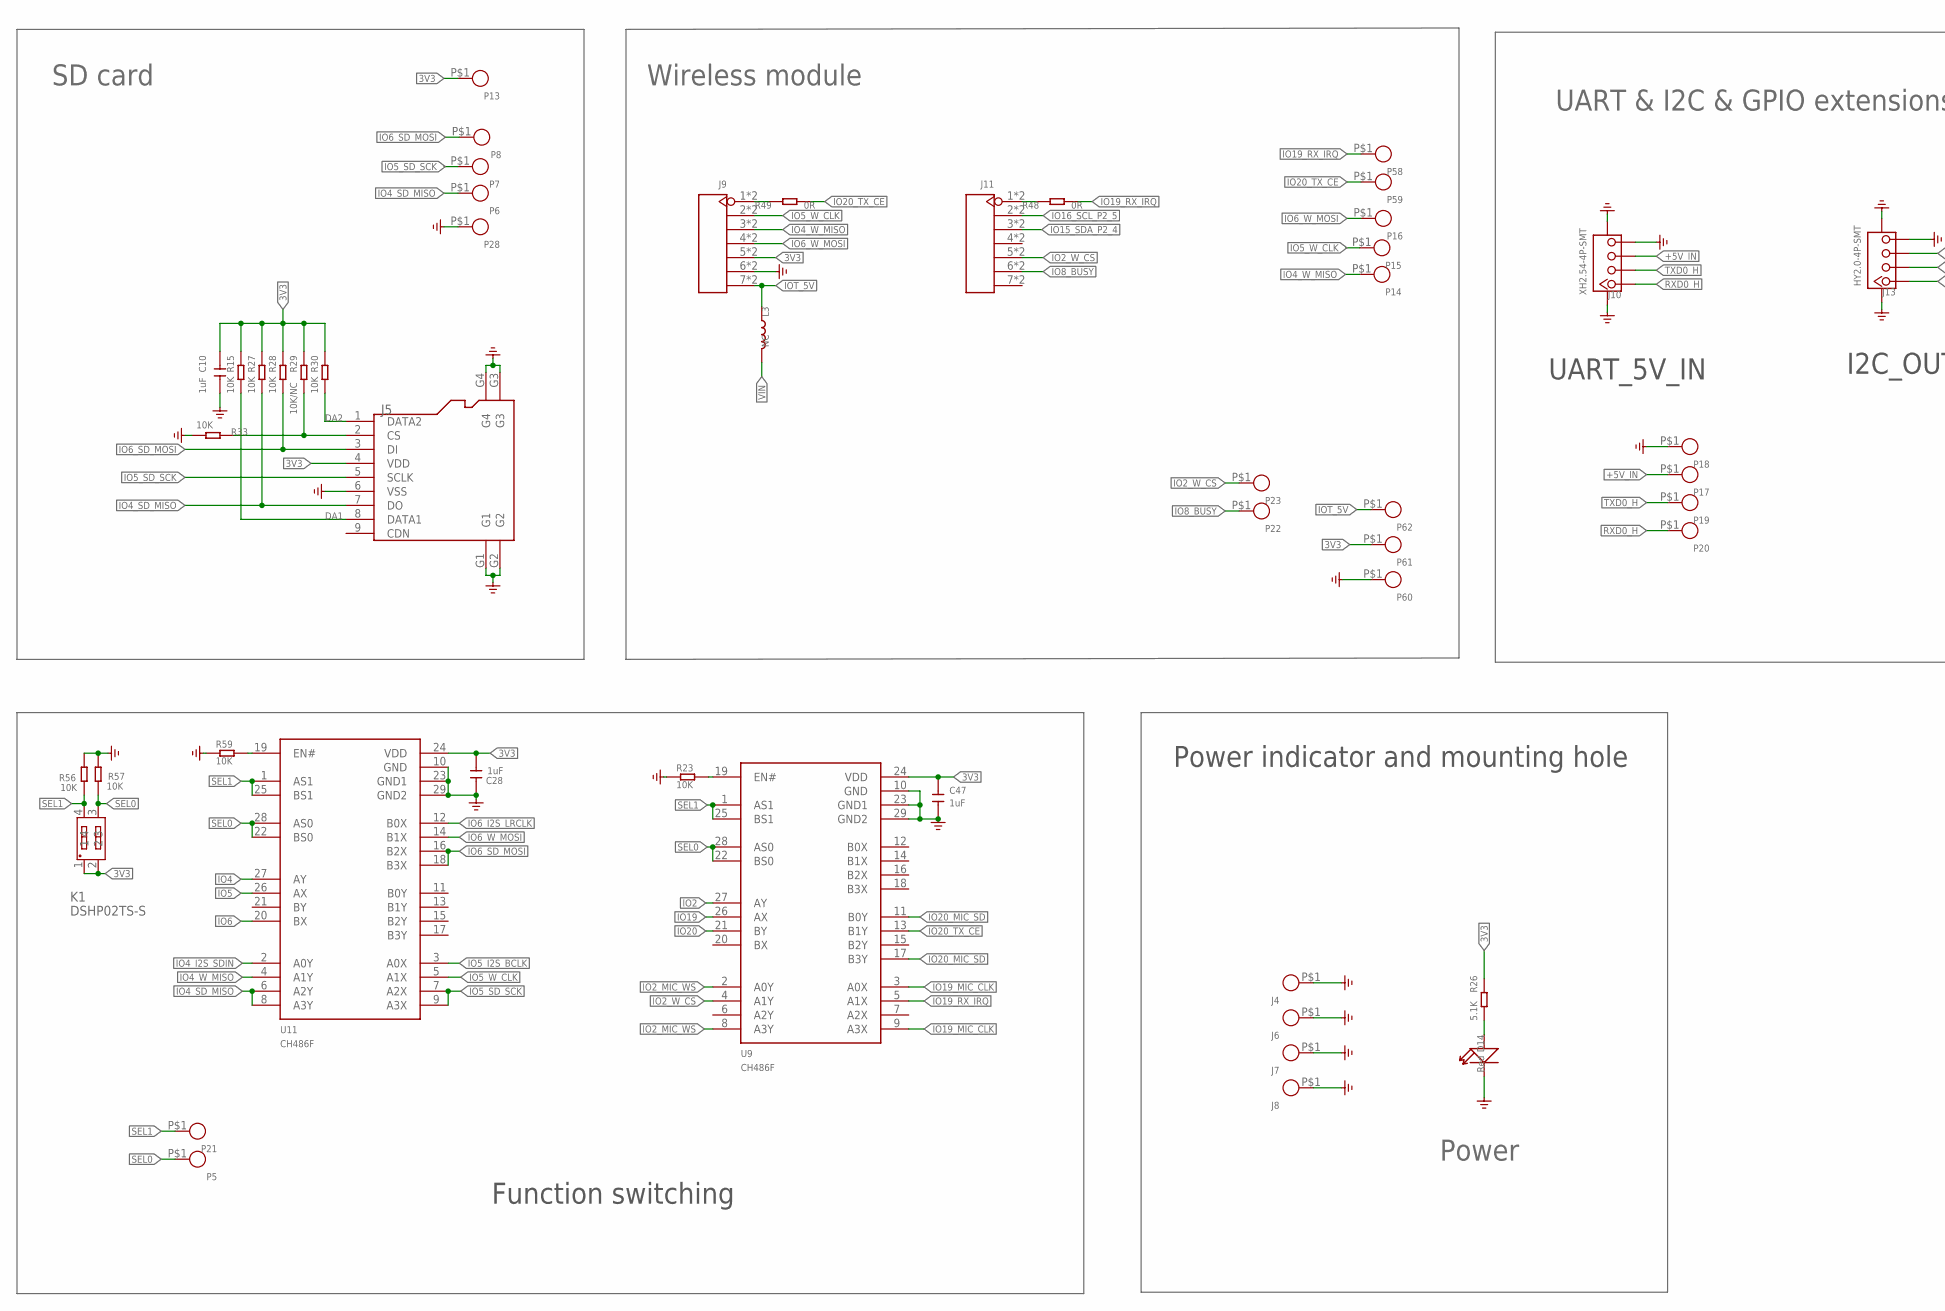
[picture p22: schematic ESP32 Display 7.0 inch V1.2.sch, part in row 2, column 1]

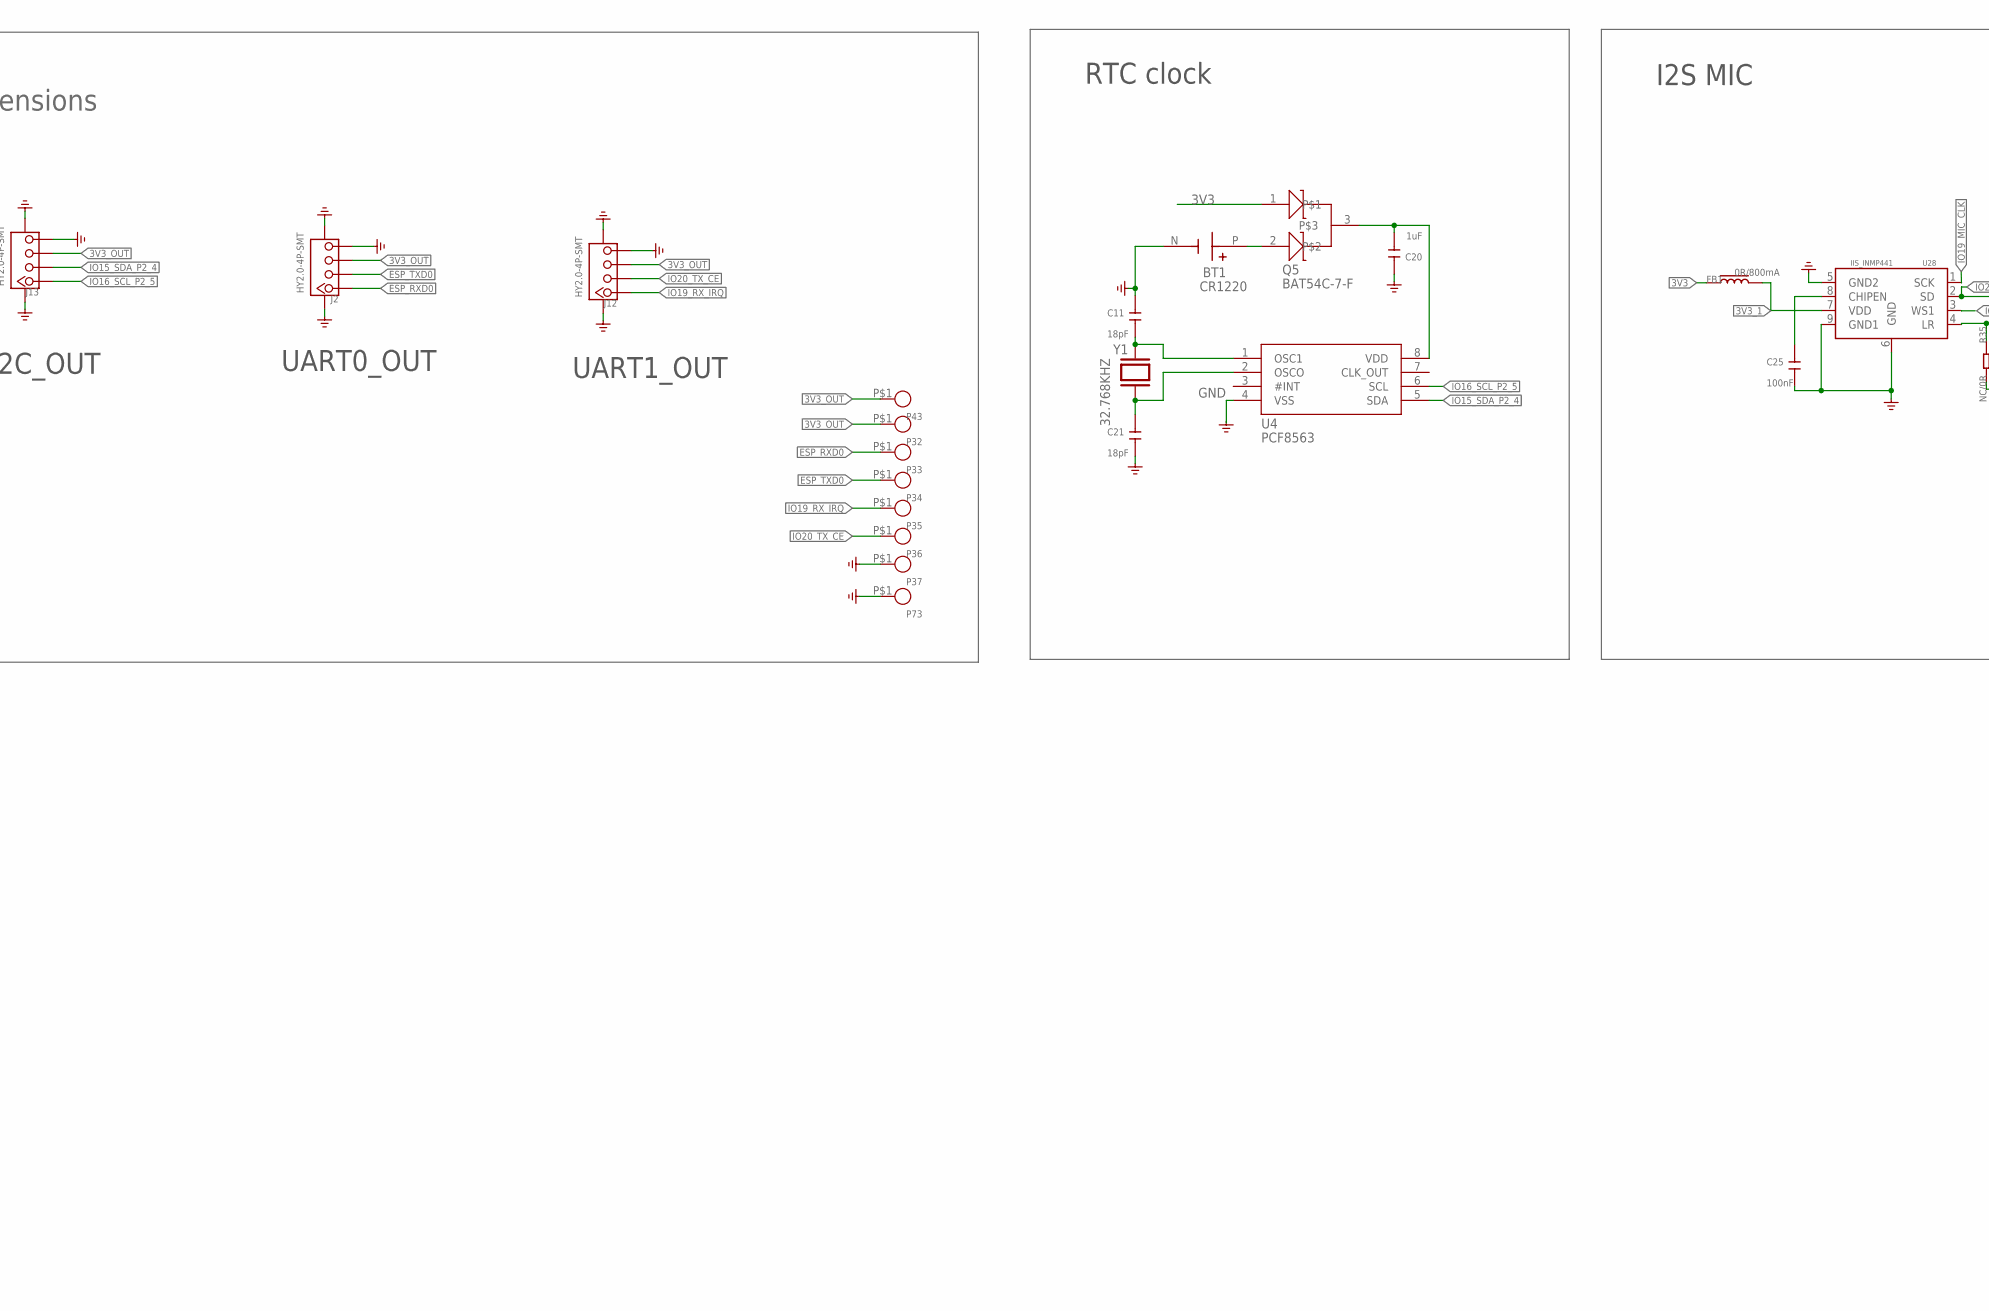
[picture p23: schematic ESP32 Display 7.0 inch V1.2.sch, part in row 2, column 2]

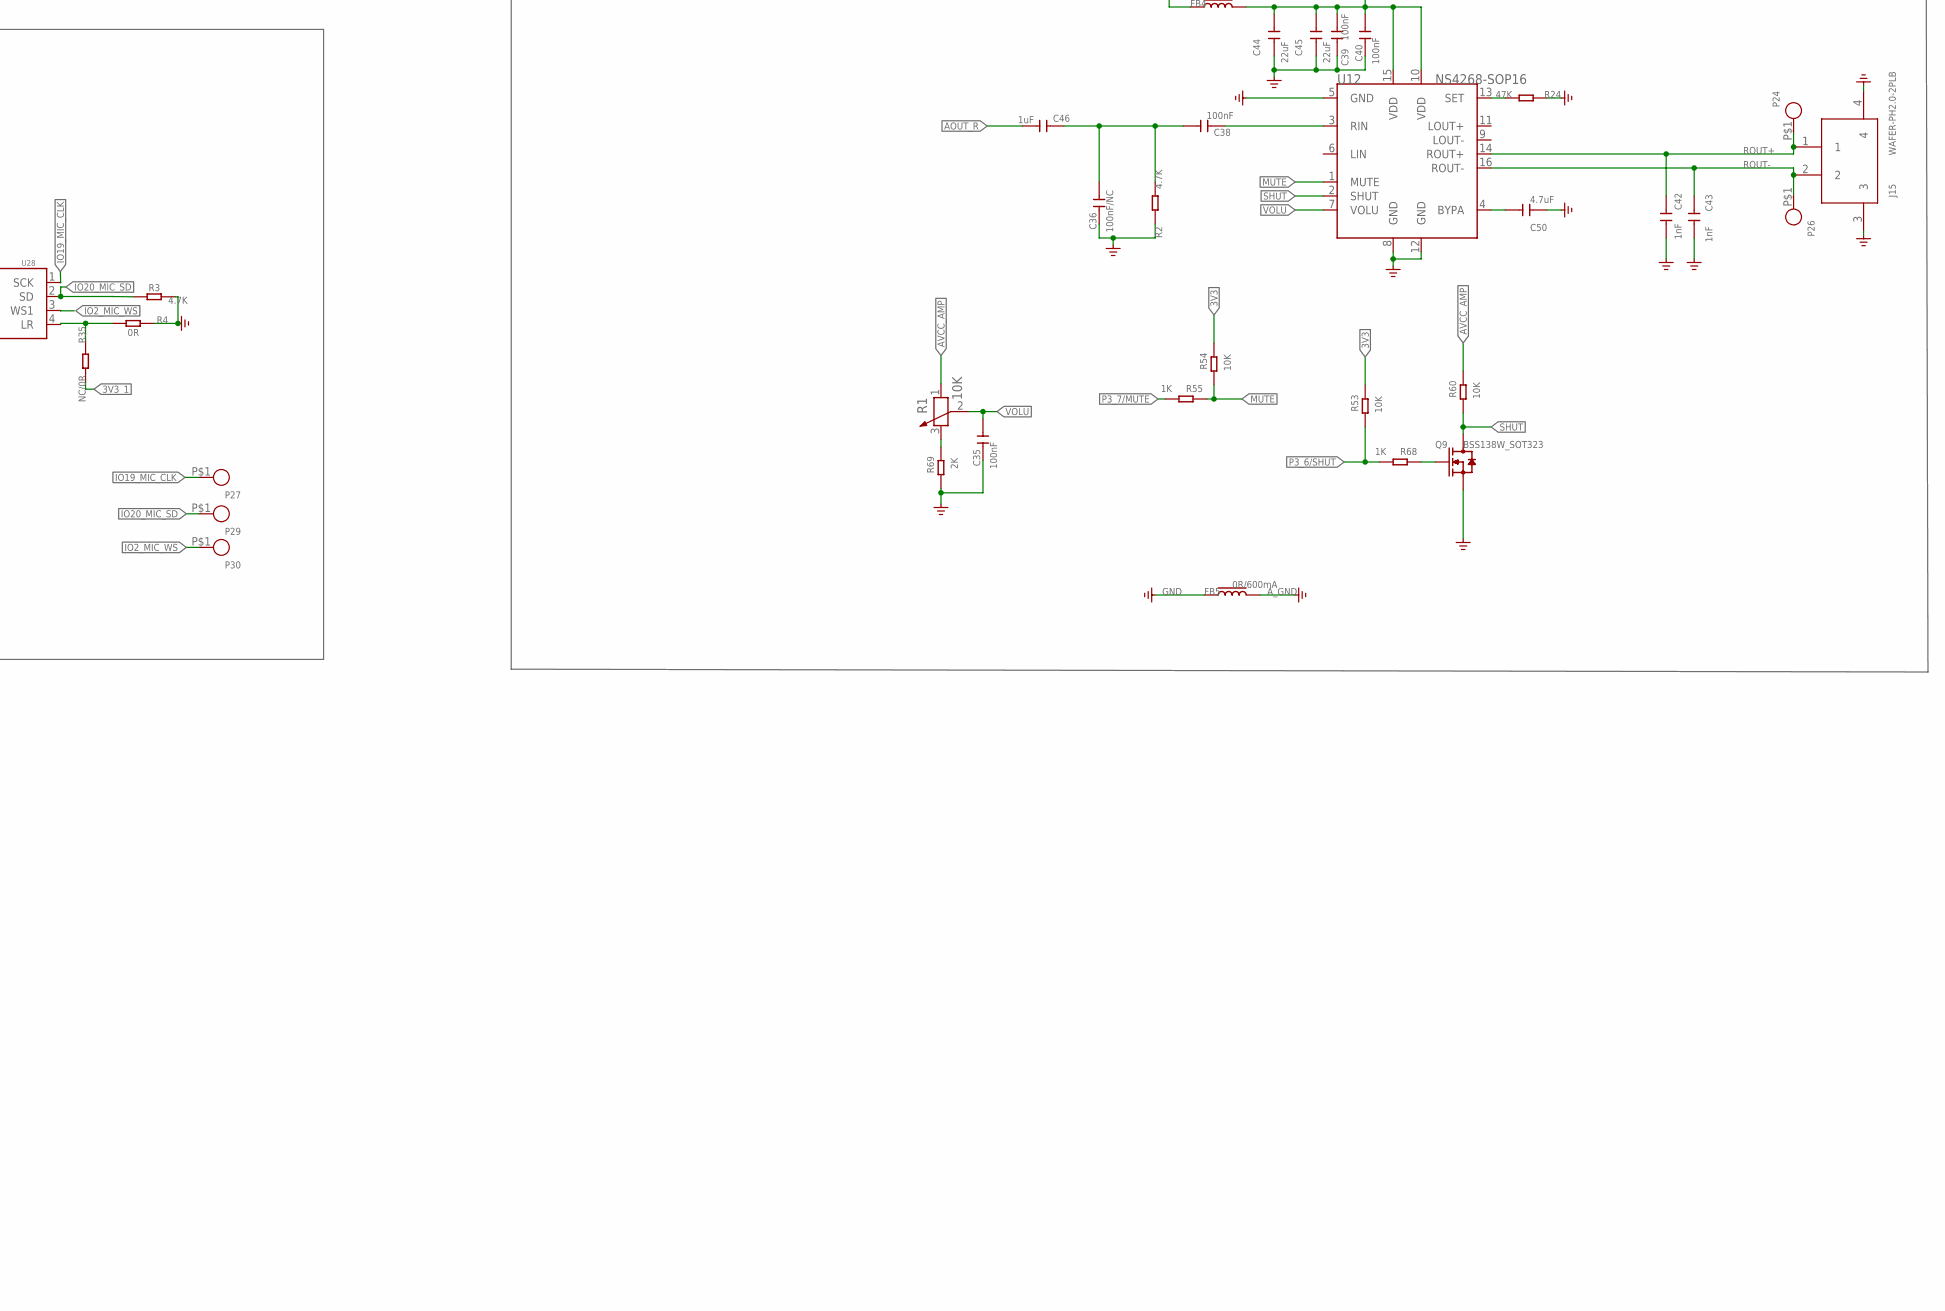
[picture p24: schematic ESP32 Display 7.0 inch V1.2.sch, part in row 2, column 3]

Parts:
B2: BEEP_5025
BT1: CR1220
C1, C2, C3, C8, C9, C10, C16, C17, C20, C22, C24, C28, C46, C47: 1uF; C0603
C4: 10uF/NC; C0603
C5, C6, C7, C13, C18, C44, C45: 22uF; C0805
C11, C21: 18pF; C0603
C12, C14, C33: 10uF; C0603
C15, C19, C23, C25, C26, C32, C35, C38, C39, C40: 100nF; C0603
C31: 47uF; C0805
C34, C42, C43: 1nF; C0603
C36: 100nF/NC; C0603
C50: 4.7uF; C0603
D1: KT-0603RYG; LED_KT-0603RYG
D2, D3, D10: DSS34; D_SOD123FL
D4, D11: 1N5817WS; D_SOD323
D6, D8: B5819WT; D_SOD523
D14: Red; LED0603
FB1, FB2, FB3: 0R/800mA; L0603
FB4, FB5: 0R/600mA; L0603
FPC1: TFT-7.0_LCD-50P; FPC-P0.5MM-50P-SMD
FPC2: FPC-6PIN-0.5MM
J1: TYPEC-3.0-16P-SMD; USB-3.0TYPEC-SMD
J2, J12, J13: HY2.0-4P-SMT; CONNECTOR_4P-SMD-2.0
J3: PH2.0WT-2PIN
J4, J6, J7, J8: THO-M3.25MM-HOLE; THO-M3.2*5MM-HOLE
J5: HOLDER-MICROSD-9P; 9P-SMD-W/-RING
J9, J11: HEADER-7P-18.28X2.5; H7-2.54-18.28X2.5X5MM
J10: XH2.54-4P-SMT; XH2.54-4P-SMD
J14: HC-PZ200-8.7L-1X4PZ1; TEST-PIN-4-2.0MM
J15: WAFER-PH2.0-2PLB; CONN-TH_2P-P2.00_XUNPU_WAFER-PH2.0-2PLB
K1: DSHP02TS-S; SW-SMD_DSHP02TS-S_1
K3, K4: KEY-4.5X4.5; KEY-4.5X4.5-SMD
L1, L2: 4.7uH/3A; L0420
L3: NC; L0603
P1, P2, P3, P4, P5, P6, P7, P8, P9, P10, P11, P12, P13, P14, P15, P16, P17, P18, P19, P20, P21, P22, P23, P24, P25, P26, P27, P28, P29, P30, P32, P33, P34, P35, P36, P37, P38, P39, P40, P41, P43, P44, P45, P46, P47, P48, P49, P50, P51, P52, P53, P54, P55, P56, P57, P58, P59, P60, P61, P62, P63, P64, P65, P66, P67, P68, P69, P70, P71, P72, P73, P75, P76: TEST_PADPAD-1.5MM; TEST_PAD-1.5MM
Q1, Q2, Q9: BSS138W_SOT323; MOS_SOT323
Q3, Q4, Q6: AO3401; PMOS_SOT23
Q5: BAT54C-7-F; SOT-23
Q7, Q8: SS8050W-SOT323; MOS_SOT323
R1: 10K; 3P-SMD-SQUA-3.6X3.3
R2, R3, R11, R12, R13, R14, R25, R34: 4.7K; R0603-SP
R4, R6, R7, R8, R10, R41, R43, R44, R45, R46, R48, R49, R70: 0R; R0603-SP
R5, R9, R15, R18, R20, R21, R22, R23, R27, R28, R30, R33, R39, R51, R53, R54, R56, R57, R59, R60, R63: 10K; R0603-SP
R16, R31, R69: 2K; R0603-SP
R17, R26, R32, R42, R47, R50, R62, R64, R65: 5.1K; R0603-SP
R19: 45.3K; R0603-SP
R24, R67: 47K; R0603-SP
R29, R52: 10K/NC; R0603-SP
R35: NC/0R; R0603-SP
R36, R37: 100K; R0603-SP
R38: 100R; R0603-SP
R40: 1.5R; R0603-SP
R55, R66, R68: 1K; R0603-SP
R58: NC; R0603-SP
R61: 3.9R; R0603-SP
U1: CH340K; ESOP-10-EP-150MIL
U2: TP4059-SOT23-6; SOT23-6L
U3: RY3420; IC_SOT23-5
U4: PCF8563; MSOP-8
U5: ESP32-S3-WROOM-1; ESP32-S3-WROOM-1-SMD41
U6: MT9201; COOPER_SOT23-6
U8: UMH3NTN; SOP65P210X100-6N
U9, U11: CH486F; QFN-28_L4.0-W4.0-P0.40-BL-EP2.8
U10: NS4168-ESOP-8
U12: NS4268-SOP16; SOP-16
U13: STC8H1K28-36I-LQFP32; QFP80P900X900X165-32N
U28: IIS_INMP441
Y1: 32.768KHZ; SMD3215-2P

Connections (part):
3V3: C6.2, C7.2, C8.2, C10.2, C12.2, C14.2, C15.2, C26.2, C28.2, C47.1, D1.1, D1.2, FB1.1, FB2.1, FB3.1, FPC2.5, J5.4 (VDD), J9.5, J9.5-5 (5), J14.3, K1.1, K1.2, L2.2, P13.P$1, P38.P$1, P61.P$1, Q1.1 (G), Q2.1 (G), Q4.2 (S), Q5.1, R11.1, R14.1, R15.2, R19.2, R25.2, R26.2, R27.2, R28.2, R29.2, R30.2, R34.2, R36.2, R46.2, R53.1, R54.1, R58.2, R61.2, U9.24 (VDD), U11.24 (VDD), U13.10 (VCC/AVCC), U13.11 (ADC_VREF+)
3V3$: C2.2, U1.10 (V3)
3V3_1: C25.2, FB1.2, R35.2, U28.7 (VDD), U28.8 (CHIPEN)
3V3_OUT: J2.3, J12.3, J13.3, P32.P$1, P43.P$1, Q4.3 (D)
+5V_IN: D2.+, D4.+, J10.3, P17.P$1
+VBUS1: C1.2, D10.+, D11.+, J1.A4, J1.A9, J1.B4, J1.B9, P1.P$1, U1.7 (VCC)
+VC_IN: C3.2, D4.-, D11.-, Q3.1 (G), R17.2, R18.2, R47.2, R50.2, U2.4 (VCC)
AOUT_R: C33.1, C34.2, C46.2
AVCC_AMP: C39.2, C40.2, C44.2, C45.2, FB4.2, R1.1, R60.1, U12.10 (VDD), U12.15 (VDD)
A_GND: C35.1, C36.1, C39.1, C40.1, C42.1, C43.1, C44.1, C45.1, C50.1, FB5.2, J15.3, J15.4, Q9.2 (S), R2.1, R24.1, R69.2, R70.2, U12.5 (GND), U12.8 (GND), U12.12 (GND)
DA1: J5.8 (DATA1), R15.1
DA2: J5.1 (DATA2), R30.1
DTR: R5.2, U1.4 (DTR#), U8.4 (E2)
ESP32_EN: C16.2, D6.-, K4.2, R22.2, U5.3 (EN), U8.6 (C1), U13.9 (P5.4)
ESP_3V3: FB2.2, R22.1, U5.2 (3V3)
ESP_RXD0: J2.1, P33.P$1, Q2.2 (S), R11.2, U5.36 (RXD0)
ESP_TXD0: J2.2, P34.P$1, Q1.2 (S), R14.2, U5.37 (TXD0)
GND: BT1.N (-), C1.1, C2.1, C3.1, C4.1, C5.1, C6.1, C7.1, C8.1, C9.1, C10.1, C11.2, C12.1, C13.2, C14.1, C15.1, C16.1, C17.1, C18.2, C19.1, C20.2, C21.1, C22.1, C23.1, C24.1, C25.1, C26.1, C28.1, C31.2, C32.2, C34.1, C47.2, D14.-, FB5.1, FPC1.51 (EP2), FPC1.52 (EP1), FPC1.P$5 (GND), FPC1.P$17 (B2), FPC1.P$18 (B1), FPC1.P$19 (B0), FPC1.P$26 (G1), FPC1.P$27 (G0), FPC1.P$33 (R2), FPC1.P$34 (R1), FPC1.P$35 (R0), FPC1.P$36 (GND3), FPC1.P$38 (GND2), FPC1.P$48 (GND1), FPC2.4, FPC2.7, FPC2.8, J1.A1, J1.A12, J1.B1, J1.B12, J1.P$1, J1.P$2, J1.P$3, J1.P$4, J2.4, J2.SS1, J2.SS2, J3.P$2, J3.P$3, J3.P$4, J4.P$1, J5.6 (VSS), J5.G1, J5.G2, J5.G3, J5.G4, J6.P$1, J7.P$1, J8.P$1, J9.6, J9.6-6 (6), J10.4, J10.5 (SS1), J10.6 (SS2), J12.4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
IO0_BOOT: K3.2, U5.27 (IO0), U8.3 (C2)
IO1_TP_INT: FPC2.3, P75.P$1, R42.2, U5.39 (IO1)
IO2: U5.38 (IO2), U9.27 (AY)
IO2_MIC_WS: P30.P$1, U9.2 (A0Y), U9.8 (A3Y), U28.3 (WS1)
IO2_W_CS: J11.5, J11.5-5 (5), P23.P$1, U9.4 (A1Y)
IO3_R6: FPC1.P$29 (R6), P51.P$1, U5.15 (IO3)
IO4: U5.4 (IO4), U11.27 (AY)
IO4_I2S_SDIN: R45.2, U11.2 (A0Y)
IO4_SD_MISO: J5.7 (DO), P6.P$1, R27.1, U11.6 (A2Y), U11.8 (A3Y)
IO4_W_MISO: J9.3, J9.3-3 (3), P14.P$1, U11.4 (A1Y)
IO5: U5.5 (IO5), U11.26 (AX)
IO5_I2S_BCLK: R44.2, U11.3 (A0X)
IO5_SD_SCK: J5.5 (SCLK), P7.P$1, U11.7 (A2X), U11.9 (A3X)
IO5_W_CLK: J9.2, J9.2-2 (2), P15.P$1, U11.5 (A1X)
IO6: U5.6 (IO6), U11.20 (BX)
IO6_I2S_LRCLK: R43.2, U11.12 (B0X)
IO6_SD_MOSI: J5.3 (DI), P8.P$1, R28.1, U11.16 (B2X), U11.18 (B3X)
IO6_W_MOSI: J9.4, J9.4-4 (4), P16.P$1, U11.14 (B1X)
IO7_R3: FPC1.P$32 (R3), P48.P$1, U5.7 (IO7)
IO8_BUSY: J11.6, J11.6-6 (6), P22.P$1, U5.12 (IO8)
IO9_G2: FPC1.P$25 (G2), P53.P$1, U5.17 (IO9)
IO10_G3: FPC1.P$24 (G3), P54.P$1, U5.18 (IO10)
IO11_G4: FPC1.P$23 (G4), P55.P$1, U5.19 (IO11)
IO12_G5: FPC1.P$22 (G5), P56.P$1, U5.20 (IO12)
IO13_G6: FPC1.P$21 (G6), P57.P$1, U5.21 (IO13)
IO14_G7: FPC1.P$20 (G7), P63.P$1, U5.22 (IO14)
IO15_SDA_P2_4: FPC2.2, J11.3, J11.3-3 (3), J13.2, P39.P$1, R25.1, U4.5 (SDA), U5.8 (IO15), U13.16 (P3.3)
IO16_SCL_P2_5: FPC2.1, J11.2, J11.2-2 (2), J13.1, P40.P$1, R34.1, U4.6 (SCL), U5.9 (IO16), U13.15 (P3.2)
IO17_R4: FPC1.P$31 (R4), P49.P$1, U5.10 (IO17)
IO18_R5: FPC1.P$30 (R5), P50.P$1, U5.11 (IO18)
IO19: U5.13 (IO19), U9.26 (AX)
IO19_MIC_CLK: P27.P$1, U9.3 (A0X), U9.9 (A3X), U28.1 (SCK)
IO19_RX_IRQ: J12.1, P35.P$1, P58.P$1, R48.2, U9.5 (A1X)
IO20: U5.14 (IO20), U9.21 (BY)
IO20_MIC_SD: P29.P$1, R3.1, U9.11 (B0Y), U9.17 (B3Y), U28.2 (SD)
IO20_TX_CE: J12.2, P36.P$1, P59.P$1, R49.2, U9.13 (B1Y)
IO21_B3: FPC1.P$16 (B3), P64.P$1, U5.23 (IO21)
IO38_B7: FPC1.P$12 (B7), P68.P$1, U5.31 (IO38)
IO39_CLK_DCLK: P69.P$1, R41.2, U5.32 (IO39)
IO40_HSYNC: FPC1.P$11 (HSYNC), P70.P$1, U5.33 (IO40)
IO41_VSYNC: FPC1.P$10 (VSYNC), P71.P$1, U5.34 (IO41)
IO42_DE: FPC1.P$9 (DE), P72.P$1, U5.35 (IO42)
IO45_B6: FPC1.P$13 (B6), P67.P$1, U5.26 (IO45)
IO46_R7: FPC1.P$28 (R7), P52.P$1, U5.16 (IO46)
IO47_B4: FPC1.P$15 (B4), P65.P$1, U5.24 (IO47)
IO48_B5: FPC1.P$14 (B5), P66.P$1, U5.25 (IO48)
IOT_5V: J9.7, J9.7-7 (7), L3.1, P62.P$1
LCD_LEDA: C18.1, C19.2, D3.-, FPC1.P$1 (VLED2+), FPC1.P$2 (VLED1+), P47.P$1, U6.5 (5-OV)
LCD_LEDK: FPC1.P$3 (VLED2-), FPC1.P$4 (VLED1-), P46.P$1, R40.2, U6.3 (3-FB)
MUTE: R54.2, R55.1, U12.1 (MUTE)
unnamed: C38.1, U12.3 (RIN)
unnamed: C36.2, C38.2, C46.1, R2.2
unnamed: R36.1, U10.1 (CTRL)
unnamed: R6.1, U1.1 (UD+)
unnamed: R7.1, U1.2 (UD-)
unnamed: R5.1, U8.2 (B1)
unnamed: R9.1, U8.5 (B2)
unnamed: R4.2, R35.1, U28.4 (LR)
unnamed: R8.2, U1.9 (RXD)
unnamed: R10.2, U1.8 (TXD)
unnamed: R16.2, U2.6 (PRO)
unnamed: Q8.1 (B), R66.1, R67.1
unnamed: L2.1, U3.3 (SW)
unnamed: R19.1, R20.2, U3.5 (FB)
unnamed: Q4.1 (G), R21.2
unnamed: R23.1, U9.19 (EN#)
unnamed: BT1.P (+), Q5.2
unnamed: D1.3, R31.1
unnamed: D1.4, R32.1
unnamed: D14.+, R26.1
unnamed: D3.+, L1.2, U6.1 (1-SW)
unnamed: J9.1, J9.1-1 (1), R49.1
unnamed: J11.1, J11.1-1 (1), R48.1
unnamed: C20.1, Q5.3, U4.8 (VDD)
unnamed: C21.2, U4.2 (OSCO), Y1.2
unnamed: R43.1, U10.2 (LRCLK)
unnamed: Q6.1 (G), Q7.3 (C), R37.1
unnamed: C11.1, U4.1 (OSC1), Y1.1
unnamed: R44.1, U10.3 (BCLK)
unnamed: Q7.1 (B), R38.1, R39.1
unnamed: R45.1, U10.4 (SDATA)
unnamed: R1.3 (2), R69.1
unnamed: FPC1.P$8 (MODE), R51.2, R52.1
unnamed: C31.1, C32.1, R46.1, U10.6 (VDD)
unnamed: R59.1, U11.19 (EN#)
unnamed: R24.2, U12.13 (SET)
unnamed: C33.2, U10.8 (VOP)
unnamed: C50.2, U12.4 (BYPA)
unnamed: Q9.1 (G), R68.1
unnamed: J1.B5, R64.2
unnamed: J1.A5, R65.1
unnamed: B2.2 (-), D8.+, Q8.3 (C)
unnamed: B2.1 (+), D8.-, R61.1
unnamed: FPC1.P$37 (DCLK), R41.1
P1_1/LED_BK_EN: R63.2, U6.4 (4-EN), U13.2 (ADC1/P1.1)
P1_3/DONE: R47.1, U2.5 (STD), U13.4 (ADC3/P1.3)
P1_4/CHRG: R50.1, U2.1 (CHG), U13.5 (ADC4/P1.4)
P1_5/D_LED: R31.2, U13.6 (ADC5/P1.5)
P1_6/C_LED: R32.2, U13.7 (ADC6/P1.6)
P1_7/TP_RST: FPC2.6, P76.P$1, R62.2, U13.8 (ADC7/P1.7)
P2_7/BEEP: R66.2, U13.28 (P2.7)
P3_5/LCD_BK_PWR: R38.2, U13.18 (P3.5)
P3_6/SHUT: R53.2, R68.2, U13.19 (P3.6)
P3_7/MUTE: R55.2, U13.20 (P3.7)
ROUT+: C42.2, J15.1, P24.P$1, U12.14 (ROUT+)
ROUT-: C43.2, J15.2, P26.P$1, U12.16 (ROUT-)
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

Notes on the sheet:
BOOT
RESET
HIG: SPI Boot
LOW: Download Boot
HIG: ESP32 Enable
LOW: ESP32 Off
Power
USB interface
Automatic download circuit
Battery and control
RTC clock
ESP32-S3-N16R8
7.0 inch IPS interface
Capacitive touch interface
DC-DC Step Down
SD card
Wireless module
UART & I2C & GPIO extensions
Power indicator and mounting hole
I2C>IO extension
I2S MIC
Power amplifier
Right channel
Passive buzzer
Function switching
UART_5V_IN
I2C_OUT
UART0_OUT
UART1_OUT

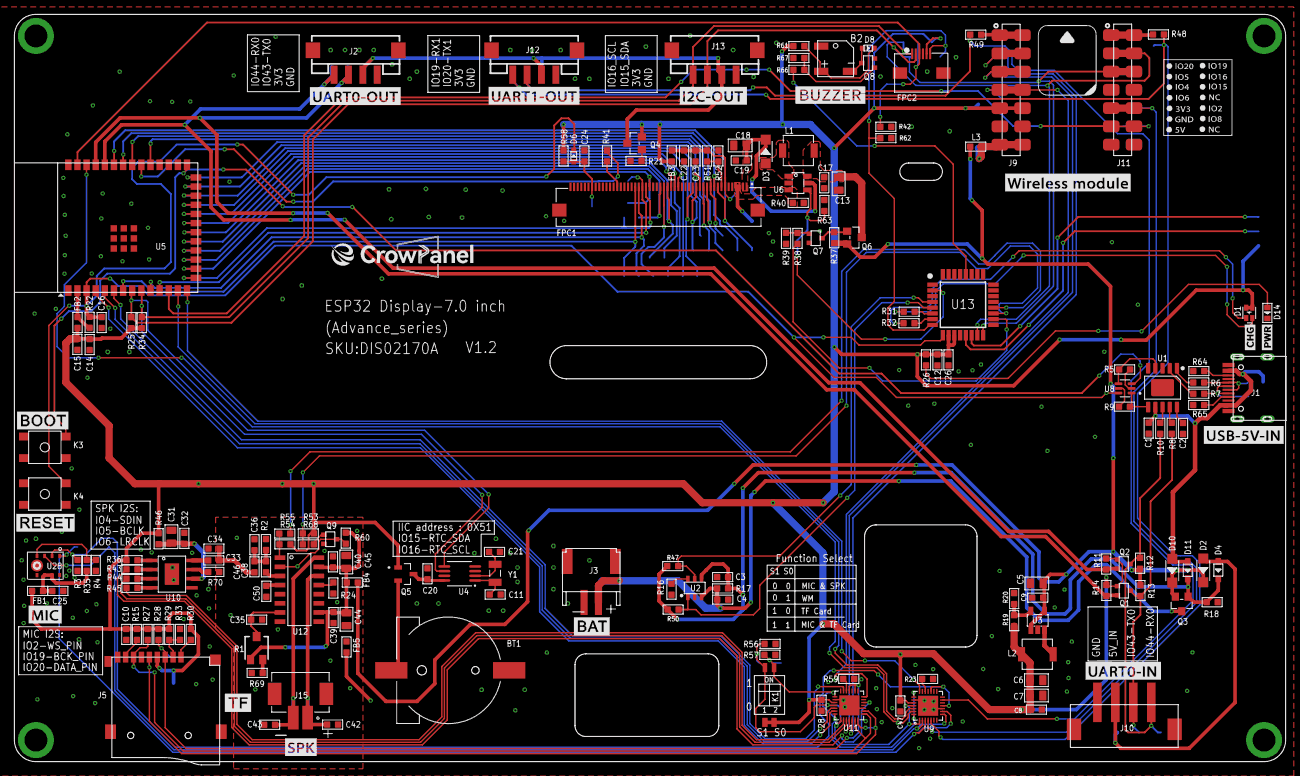
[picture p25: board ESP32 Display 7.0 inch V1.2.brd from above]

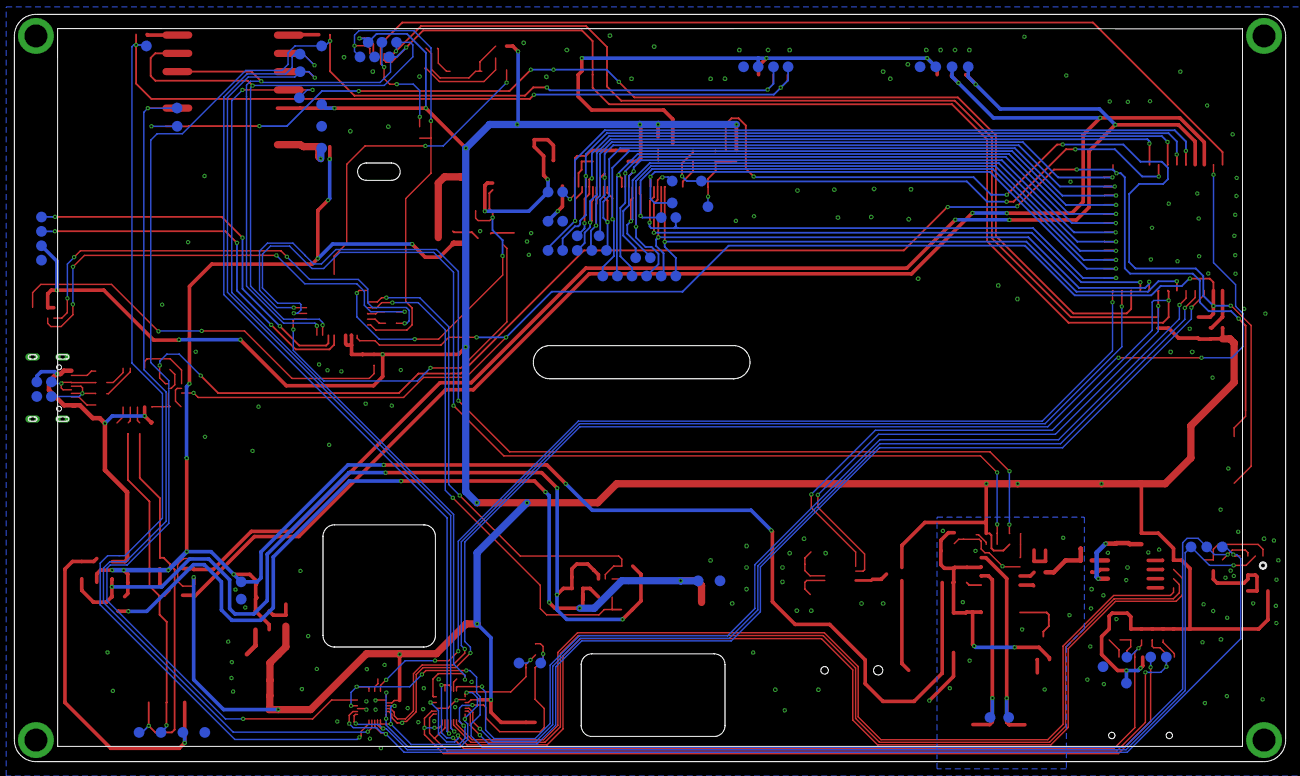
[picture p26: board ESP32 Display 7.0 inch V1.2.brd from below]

Board: 2 copper layers, 176.9 x 104.0 mm, 248 parts (74 on the bottom side), 141 nets.

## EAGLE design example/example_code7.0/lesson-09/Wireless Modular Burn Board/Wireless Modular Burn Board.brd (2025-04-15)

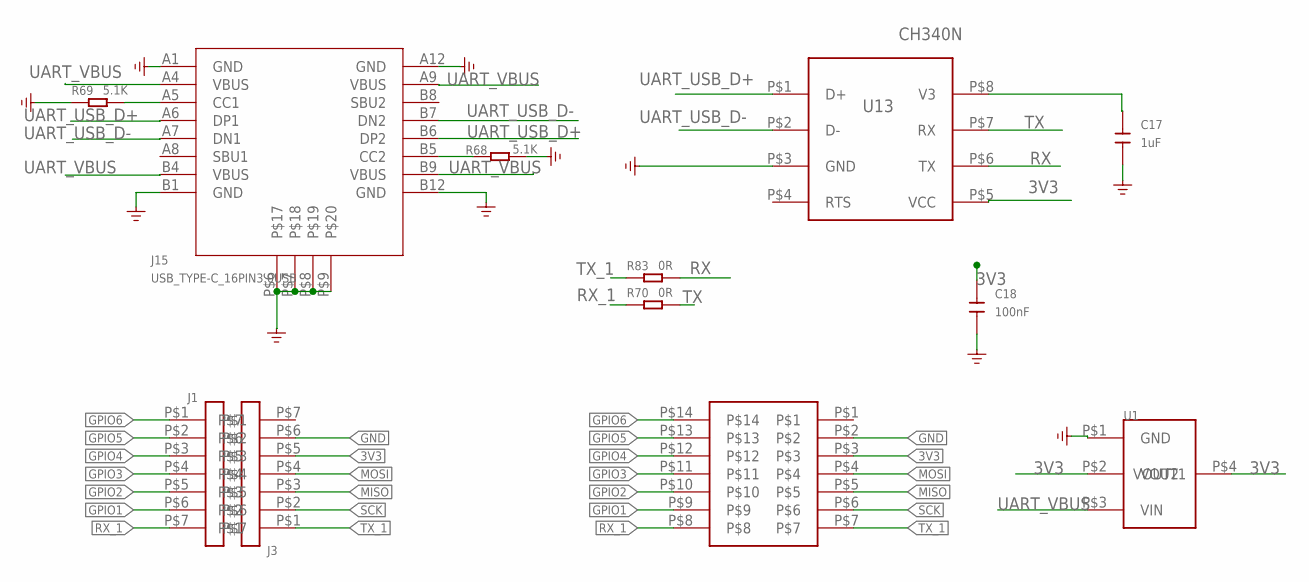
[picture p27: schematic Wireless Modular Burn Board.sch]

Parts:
C17: 1uF; 0603
C18: 100nF; 0603
J1, J3: 2.54MM-7P
J2: SMT-2.54MM-7P
J15: USB_TYPE-C_16PIN3.0USB; KEVIN_3.0TYPEC-SMD
R68, R69: 5.1K; DISCRETE_R0603
R70, R83: 0R; DISCRETE_R0603
U1: AMS1117-3V3; SOT-223
U13: CH340N; SOP8

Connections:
3V3: C18.2, J2.P$3, J3.P$5, U1.P$2 (VOUT1), U1.P$4 (VOUT2), U13.P$5 (VCC)
GND: C17.1, C18.1, J2.P$2, J3.P$6, J15.A1 (GND), J15.A12 (GND), J15.B1 (GND), J15.B12 (GND), J15.P$6, J15.P$7, J15.P$8, J15.P$9, R68.2, R69.1, U1.P$1 (GND), U13.P$3 (GND)
GPIO1: J1.P$6, J2.P$9
GPIO2: J1.P$5, J2.P$10
GPIO3: J1.P$4, J2.P$11
GPIO4: J1.P$3, J2.P$12
GPIO5: J1.P$2, J2.P$13
GPIO6: J1.P$1, J2.P$14
MISO: J2.P$5, J3.P$3
MOSI: J2.P$4, J3.P$4
unnamed: J15.B5 (CC2), R68.1
unnamed: J15.A5 (CC1), R69.2
unnamed: C17.2, U13.P$8 (V3)
RX: R83.2, U13.P$6 (TX)
RX_1: J1.P$7, J2.P$8, R70.1
SCK: J2.P$6, J3.P$2
TX: R70.2, U13.P$7 (RX)
TX_1: J2.P$7, J3.P$1, R83.1
UART_USB_D+: J15.A6 (DP1), J15.B6 (DP2), U13.P$1 (D+)
UART_USB_D-: J15.A7 (DN1), J15.B7 (DN2), U13.P$2 (D-)
UART_VBUS: J15.A4 (VBUS), J15.A9 (VBUS), J15.B4 (VBUS), J15.B9 (VBUS), U1.P$3 (VIN)

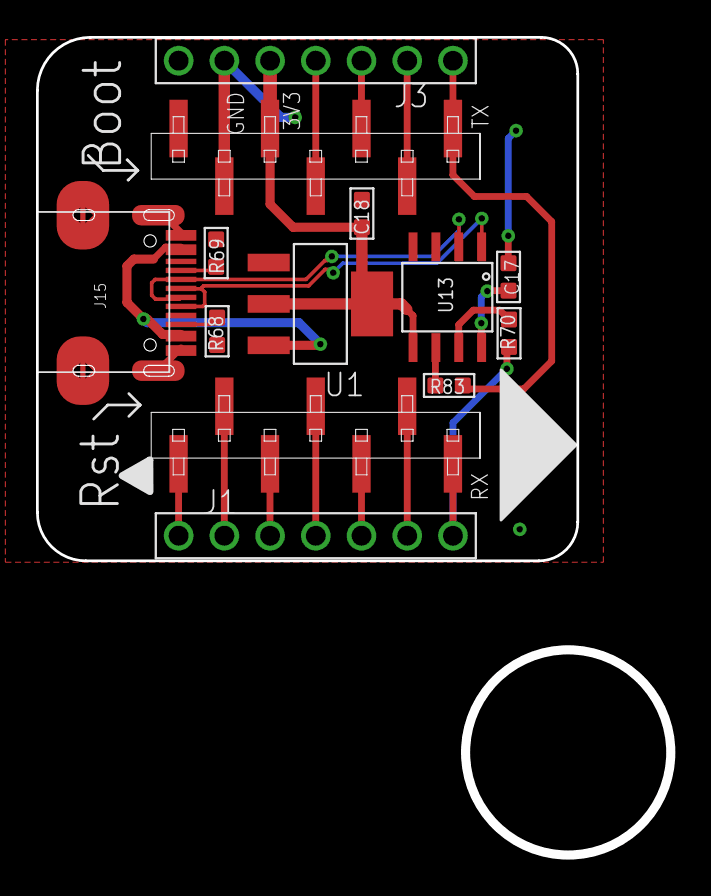
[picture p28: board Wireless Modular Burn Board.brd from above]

Board: 2 copper layers, 30.0 x 29.1 mm, 12 parts (0 on the bottom side), 21 nets.

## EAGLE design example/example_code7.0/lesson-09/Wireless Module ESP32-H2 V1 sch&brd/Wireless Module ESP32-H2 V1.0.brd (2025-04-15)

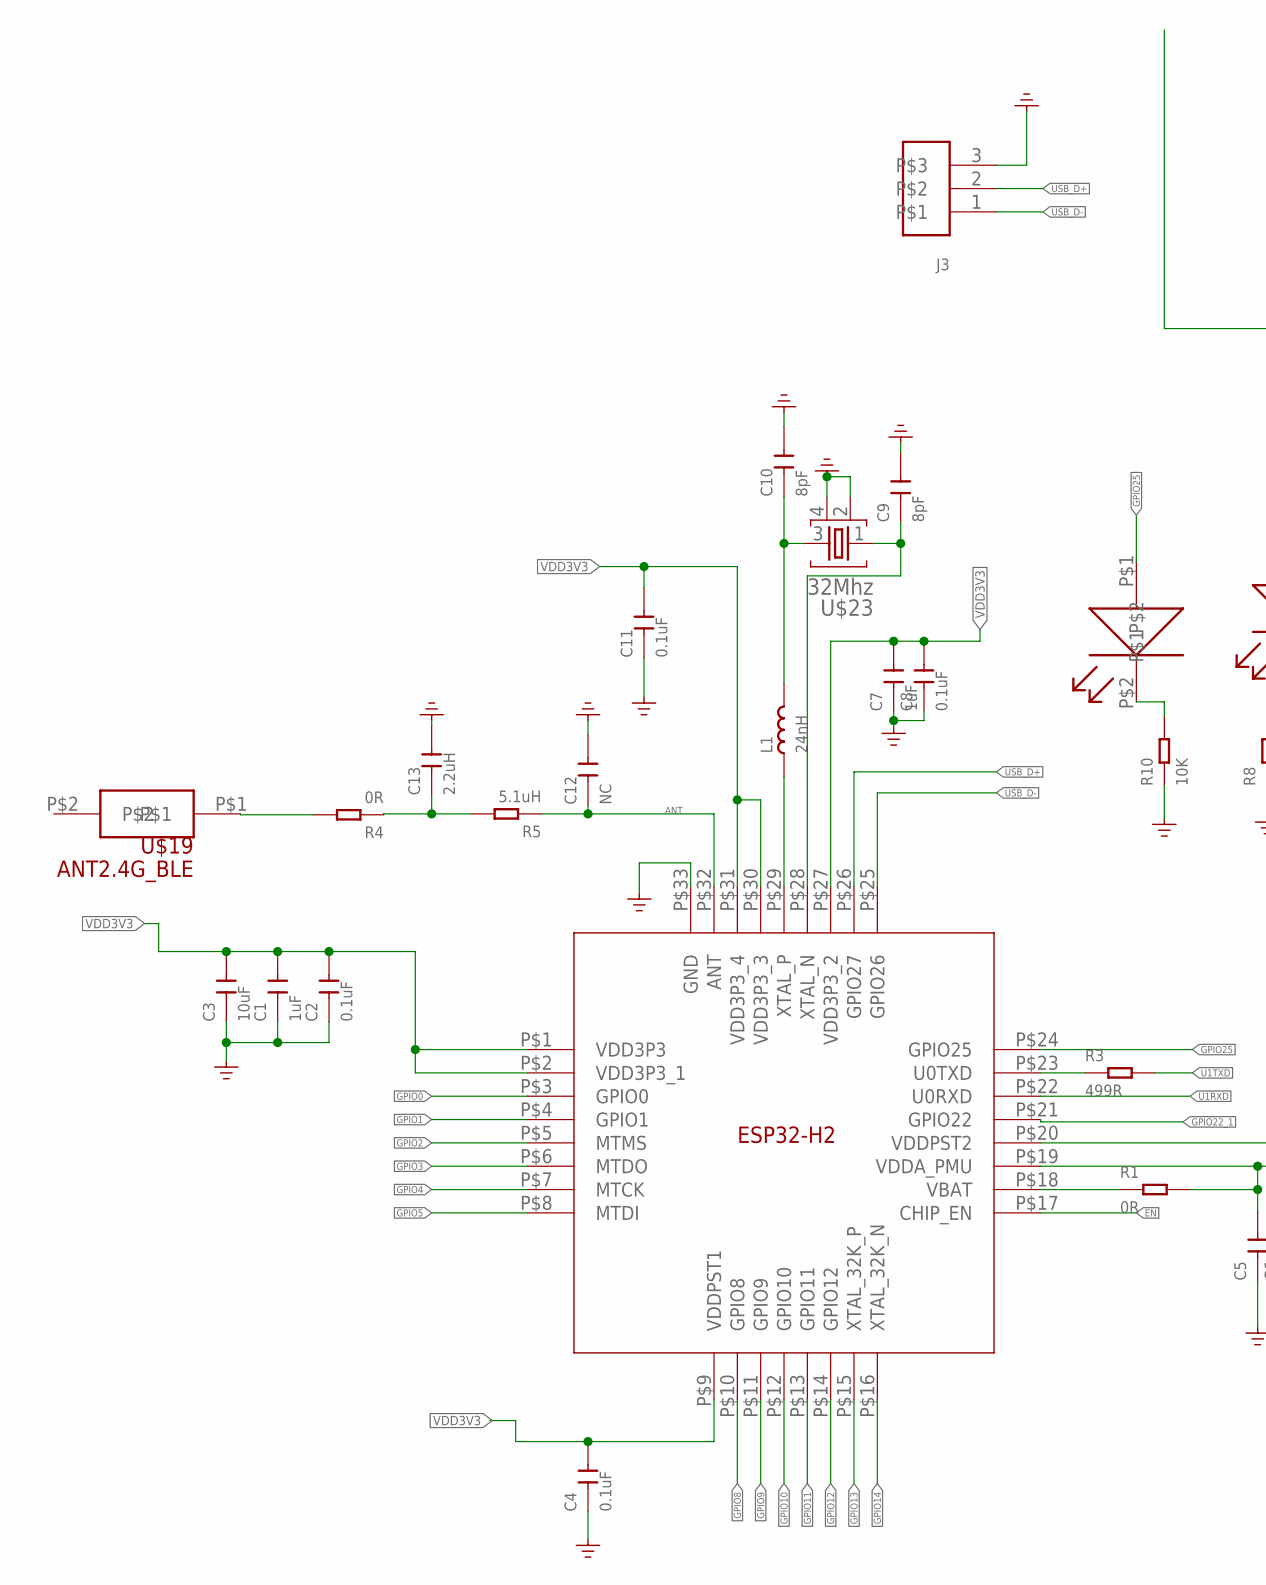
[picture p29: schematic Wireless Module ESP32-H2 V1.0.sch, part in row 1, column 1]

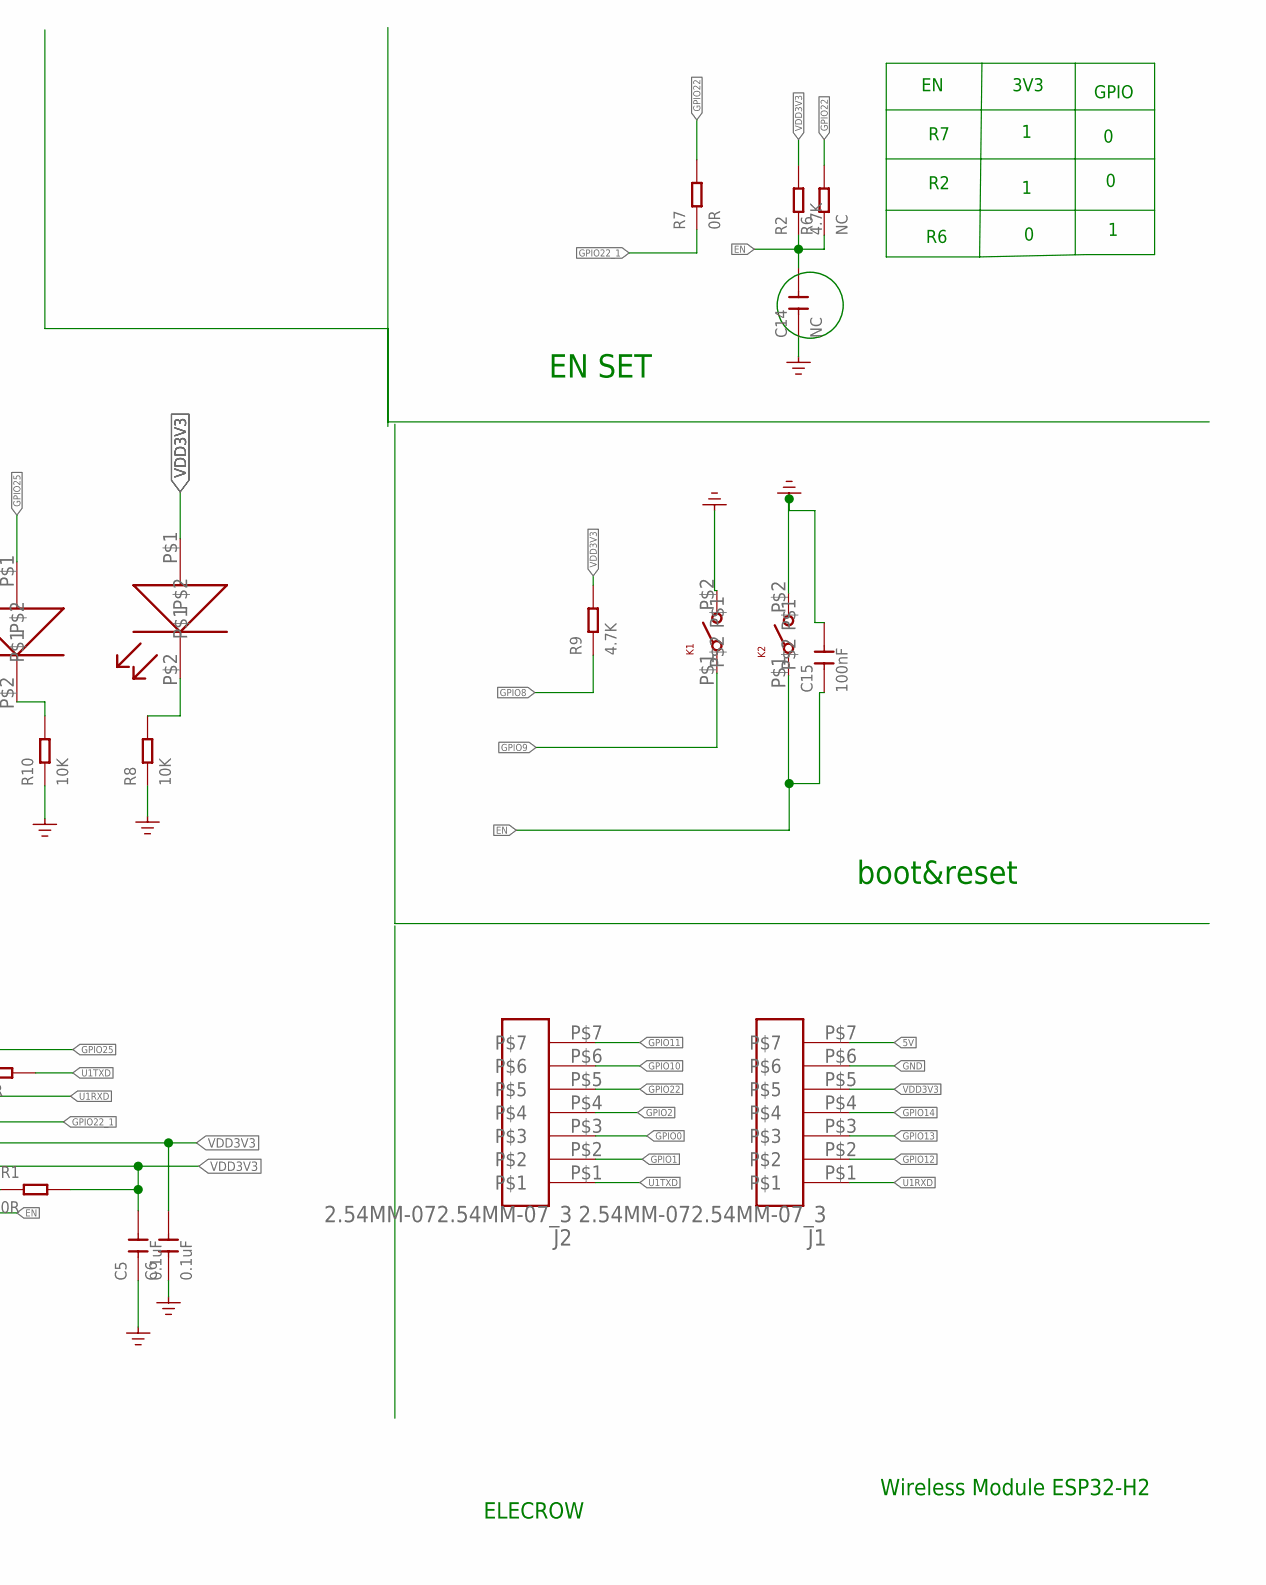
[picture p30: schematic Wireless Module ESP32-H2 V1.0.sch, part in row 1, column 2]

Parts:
C1, C7: 1uF; DISCRETE-NEW_C0402
C2, C4, C5, C6, C8, C11: 0.1uF; DISCRETE-NEW_C0402
C3: 10uF; DISCRETE-NEW_C0402
C9, C10: 8pF; DISCRETE-NEW_C0402
C12, C14: NC; DISCRETE-NEW_C0402
C13: 2.2uH; DISCRETE-NEW_C0402
C15: 100nF; DISCRETE-NEW_C0402
J1, J2: 2.54MM-072.54MM-07_3; 2.54MM-07_3
J3: 1.27MM-3P
K1, K2: KEY_SMD; KEY_3*2.5
L1: 24nH; DISCRETE-NEW_L0402
LED1, LED2: LED_SMT; LED_0402
R1, R4, R7: 0R; DISCRETE-NEW_R0402
R2, R9: 4.7K; DISCRETE-NEW_R0402
R3: 499R; DISCRETE-NEW_R0402
R5: 5.1uH; DISCRETE-NEW_R0402
R6: NC; DISCRETE-NEW_R0402
R8, R10: 10K; DISCRETE-NEW_R0402
U$1: ESP32-H2
U$19: ANT2.4G_BLE; 2.4G_BLE
U$23: 32Mhz; NORDIC_NRF_BT-XTAL_2016_N

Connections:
5V: J1.P$7
ANT: C12.1, R5.1, U$1.P$32 (ANT)
EN: C14.2, C15.1, K2.P$1, R2.1, R6.1, U$1.P$17 (CHIP_EN)
GND: C1.1, C2.1, C3.1, C4.1, C5.1, C6.1, C7.1, C8.1, C9.2, C10.2, C11.1, C12.2, C13.2, C14.1, C15.2, J1.P$6, J3.3, K1.P$2, K2.P$2, R8.1, R10.1, U$1.P$33 (GND), U$23.2, U$23.4
GPIO0: J2.P$3, U$1.P$3 (GPIO0)
GPIO1: J2.P$2, U$1.P$4 (GPIO1)
GPIO2: J2.P$4, U$1.P$5 (MTMS)
GPIO3: U$1.P$6 (MTDO)
GPIO4: U$1.P$7 (MTCK)
GPIO5: U$1.P$8 (MTDI)
GPIO8: R9.1, U$1.P$10 (GPIO8)
GPIO9: K1.P$1, U$1.P$11 (GPIO9)
GPIO10: J2.P$6, U$1.P$12 (GPIO10)
GPIO11: J2.P$7, U$1.P$13 (GPIO11)
GPIO12: J1.P$2, U$1.P$14 (GPIO12)
GPIO13: J1.P$3, U$1.P$15 (XTAL_32K_P)
GPIO14: J1.P$4, U$1.P$16 (XTAL_32K_N)
GPIO22: J2.P$5, R6.2, R7.2
GPIO22_1: R7.1, U$1.P$21 (GPIO22)
GPIO25: LED1.P$1, U$1.P$24 (GPIO25)
unnamed: C13.1, R4.1, R5.2
unnamed: R3.1, U$1.P$23 (U0TXD)
unnamed: C10.1, L1.2, U$23.3
unnamed: C9.1, U$1.P$28 (XTAL_N), U$23.1
unnamed: LED2.P$2, R8.2
unnamed: LED1.P$2, R10.2
unnamed: R4.2, U$19.P$1
unnamed: L1.1, U$1.P$29 (XTAL_P)
P$18: R1.1, U$1.P$18 (VBAT)
U1RXD: J1.P$1, U$1.P$22 (U0RXD)
U1TXD: J2.P$1, R3.2
USB_D+: J3.2, U$1.P$26 (GPIO27)
USB_D-: J3.1, U$1.P$25 (GPIO26)
VDD3V3: C1.2, C2.2, C3.2, C4.2, C5.2, C6.2, C7.2, C8.2, C11.2, J1.P$5, LED2.P$1, R1.2, R2.2, R9.2, U$1.P$1 (VDD3P3), U$1.P$2 (VDD3P3_1), U$1.P$9 (VDDPST1), U$1.P$19 (VDDA_PMU), U$1.P$20 (VDDPST2), U$1.P$27 (VDD3P3_2), U$1.P$30 (VDD3P3_3), U$1.P$31 (VDD3P3_4)

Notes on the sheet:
3V3
GPIO
EN SET
boot&reset
ELECROW
Wireless Module ESP32-H2


Board: 2 copper layers, 18.0 x 23.7 mm, 36 parts (0 on the bottom side), 30 nets.

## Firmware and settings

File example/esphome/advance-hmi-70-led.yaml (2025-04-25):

esphome:
  name: advance-hmi-43-led
  friendly_name: Advance_HMI_43_LED
  platformio_options:
    build_flags: "-DBOARD_HAS_PSRAM"
    board_build.esp-idf.memory_type: qio_opi
    board_build.flash_mode: dio

esp32:
  board: esp32-s3-devkitc-1
  framework:
    type: esp-idf
    sdkconfig_options:
      CONFIG_ESP32S3_DEFAULT_CPU_FREQ_240: y
      CONFIG_ESP32S3_DATA_CACHE_64KB: y
      CONFIG_SPIRAM_FETCH_INSTRUCTIONS: y
      CONFIG_SPIRAM_RODATA: y

psram:
  mode: octal
  speed: 80MHz 

logger:

api:
  encryption:
    key: "QBWNa46GbVW4ootHxkQtIFQ+fQyUIpWM4Xa6ggGe3vg="

ota:
  - platform: esphome
    password: "165fa4ccdfd282d4400876605ef95e8b"

wifi:
  ssid: !secret wifi_ssid
  password: !secret wifi_password
  ap:
    ssid: "Advance-Hmi-43-Led"
    password: "ce1wfZSuEaZS"

captive_portal:

switch:
  - platform: gpio
    pin: GPIO19
    name: "LED"
    id: led_output
    on_turn_on:
      # Switch bulb diagram
      - lvgl.image.update:
          id: lvgl_light
          src: light_on
      # Switch the status label text to ON
      - lvgl.label.update:
          id: label_light_state
          text: "ON"
    on_turn_off:
      # Switch bulb diagram
      - lvgl.image.update:
          id: lvgl_light
          src: light_off
      # Switch the status label text to OFF
      - lvgl.label.update:
          id: label_light_state
          text: "OFF"
          
  - platform: gpio
    name: "PCF9554A Pin #1"
    pin:
      pca9554: pca9557_device
      number: 1
      mode:
        output: true
      inverted: true

output:
  - platform: ledc
    pin:
      number: GPIO2
    id: backlight_output

light:
  - platform: monochromatic
    output: backlight_output
    name: LCD Backlight
    id: led
    restore_mode: ALWAYS_ON
    default_transition_length: 0s

image:
  - file: "small_temp.png"
    id: small_temp
    resize: 200x200
    type: RGB565
  - file: "small_hum.png"
    id: small_hum
    resize: 200x200
    type: RGB565
  - file: "small_logo.png"
    id: small_logo
    resize: 200x100
    type: RGB565
  - file: "light.png"
    id: light_on
    resize: 200x200
    type: RGB565
  - file: "no_light.png"
    id: light_off
    resize: 200x200
    type: RGB565

i2c:
  sda: 15
  scl: 16
  scan: true

pca9554:
  - id: 'pca9557_device'
    address: 0x18

sensor:
  - platform: aht10
    variant: AHT20
    temperature:
      name: "Room Temperature"
      id: room_temp
      unit_of_measurement: "°C"
      accuracy_decimals: 1
    humidity:
      name: "Room Humidity"
      id: room_hum
      unit_of_measurement: "%"
      accuracy_decimals: 1
    update_interval: 1s

display:
  - platform: rpi_dpi_rgb
    id: main_display
    color_order: RGB
    invert_colors: true
    update_interval: never
    auto_clear_enabled: false
    dimensions:
      width: 800
      height: 480
    de_pin: 42
    hsync_pin: 40
    vsync_pin: 41
    pclk_pin: 39
    pclk_frequency: 20MHz
    hsync_pulse_width: 4
    hsync_front_porch: 8
    hsync_back_porch: 8
    vsync_pulse_width: 4
    vsync_front_porch: 8
    vsync_back_porch: 8
    data_pins:
      red:
        - 7
        - 17
        - 18
        - 3
        - 46
      green:
        - 9
        - 10
        - 11
        - 12
        - 13
        - 14
      blue:
        - 21
        - 47
        - 48
        - 45
        - 38

time:
  - platform: homeassistant
    id: time_comp

lvgl:
  log_level: INFO
  color_depth: 16
  bg_color: 0xFFFFFF
  text_font: montserrat_26
  widgets:
    - image:
        id: lvgl_logo
        src: small_logo
        x: 300
        y: 20
    - image:
        id: lvgl_temp
        src: small_temp
        x: 150
        y: 250
    - image:
        id: lvgl_hum
        src: small_hum
        x: 400
        y: 250
    - image:
        id: lvgl_light
        src: light_off    # Default 'Turn off lights' image
        x: 650            # You can adjust the position by yourself
        y: 250
    - label:
        id: label_temp
        x: 90
        y: 350
        text: "Temp: --°C"
    - label:
        id: label_hum
        x: 350
        y: 350
        text: "Humi: --%"
    - label:
        id: label_light_state
        x: 650
        y: 350
        text: "OFF"

interval:
  - interval: 1s
    then:
      - lambda: |-
          char temp_str[20];
          char hum_str[20];
          snprintf(temp_str, sizeof(temp_str), "Temp: %.1f°C", id(room_temp).state);
          snprintf(hum_str, sizeof(hum_str), "Humi: %.1f%%", id(room_hum).state);
          lv_label_set_text(id(label_temp), temp_str);
          lv_label_set_text(id(label_hum), hum_str);

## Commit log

2025-03-17 Create wireless modue user burn guide.md
2025-03-17 Update wireless modue user burn guide.md
